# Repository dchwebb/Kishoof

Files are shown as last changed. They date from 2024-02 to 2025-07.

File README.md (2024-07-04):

# Kishoof

## Overview

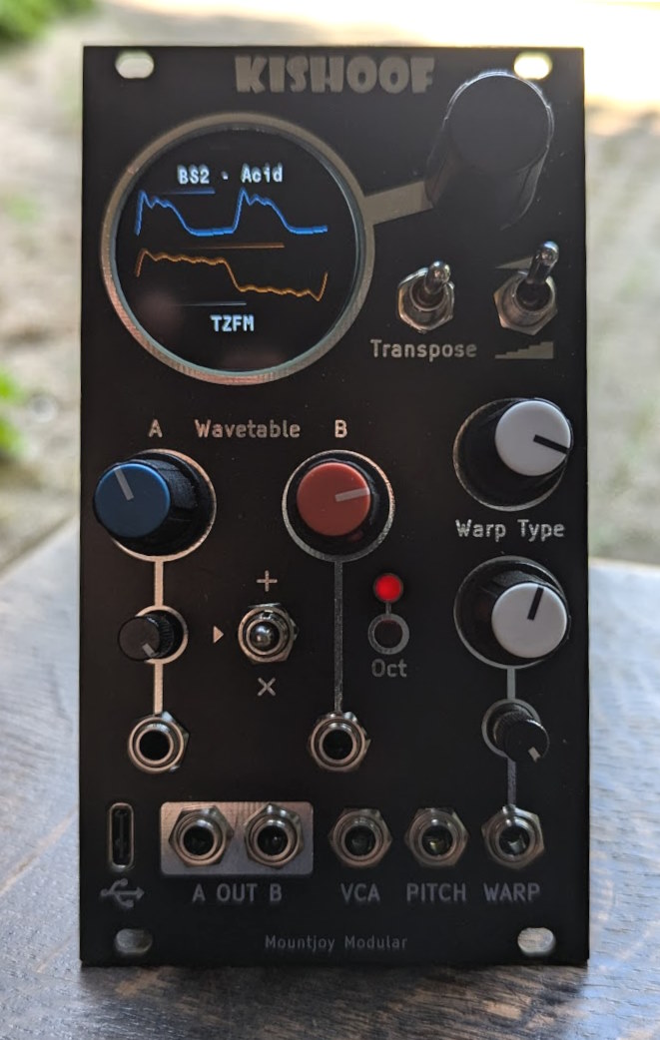
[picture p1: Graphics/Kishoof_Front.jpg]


Kishoof is a Wavetable synthesizer designed for use in a Eurorack modular system. A dual channel architecture allows simultaneous playback of two channels each offering a different range of capabilities. Wavetables are held in 64MB of internal flash storage which is exposed as a USB disk drive via a front-panel USB C connector.

Two modes of operation are available with one stepping between individual wavetable frames and one smoothly interpolating between frames. In stepped mode channel A and B can each play any of the available wavetable frames. In smooth mode Channel A plays the loaded wavetable and channel B plays an internal wavetable that can be configured to hold a range of standard waveforms and harmonics.

A warp engine allows a range of warping effects to alter channel A's signal, with Bend, Squeeze, Mirror and though-Zero Frequency Modulation from channel B available. Channel B can be modulated via addition (mixing) and multiplication (ring modulation) with channel A and its playback direction can be reversed. Dynamic anti-aliasing filters eliminate aliasing regardless of modulation settings. 

A circular TFT LCD display shows both or either channel's waveform with any warping and modulation applied. A serial console available over a USB virtual COM port allows advanced configuration, calibration and trouble-shooting facilities.

The module was designed in conjunction with musician Tal Shoshani who produced the following demonstration video:

IMAGE ALT TEXT HERE (https://www.youtube.com/watch?v=ltlQT8CrSRk)

- **[Operation Manual](Kishoof_Manual.md)**

## Technical

Kishoof is based on an STM32H7B0 microcontroller clocked at 280MHz. Internal flash storage uses a Macronix MX25LM51245G 512Mbit NOR flash IC, clocked at 76.8MHz. The flash is controlled by the MCU using OctoSPI.

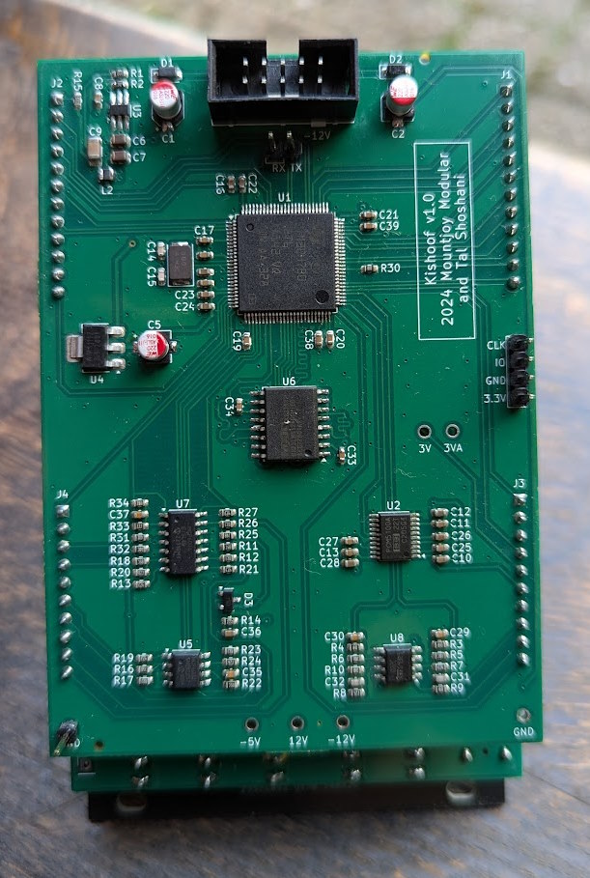
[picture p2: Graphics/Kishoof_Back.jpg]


A TI PCM5100APW audio DAC is used for wavetable playback, operating in stereo at 48KHz. This is interfaced to the MCU over I2S. The MCU's internal 12 bit ADCs receive potentiometer and scaled Control voltage inputs.

The display is a circular 1.28 inch 240x240 IPS TFT LCD with GC9A01 Driver and is controlled via SPI. USB is connected via a front-panel USB C connector with ESD Protection.

**Construction**

The module is constructed of four PCBs: Component board, Control board, LCD daughterboard and Front Panel. The Component board is a 4-layer board. All others are 2 layer.

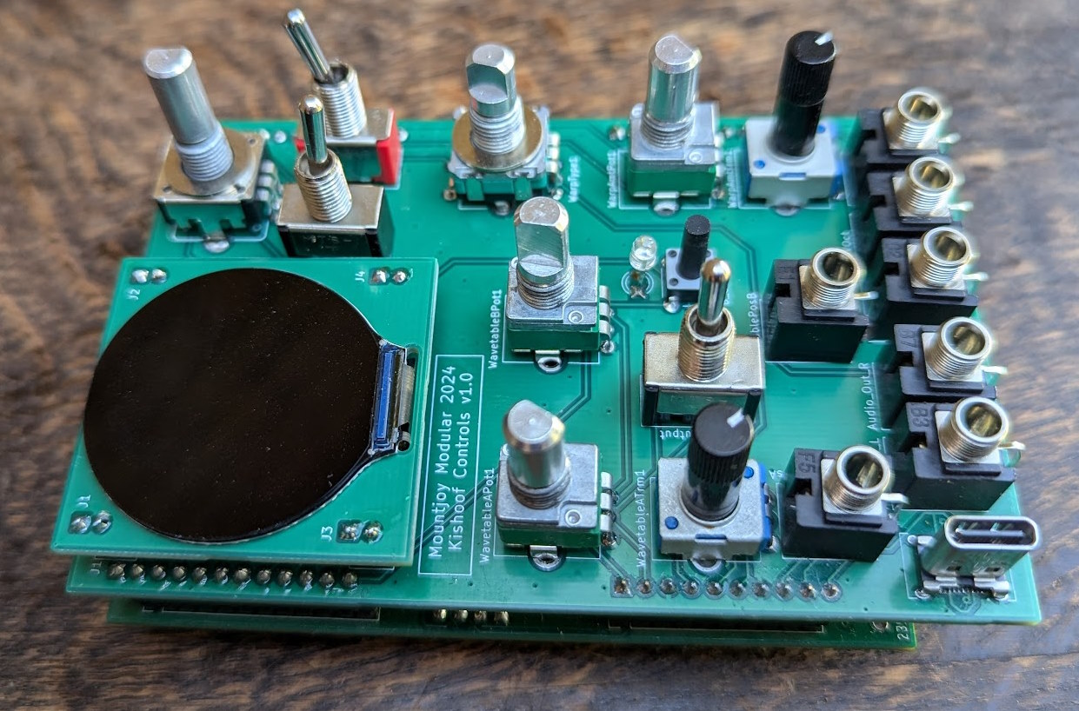
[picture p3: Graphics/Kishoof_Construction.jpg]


Circuit Design and layout using Kicad v8:

[Components schematic](Hardware/Kishoof_Components.pdf)

[Controls schematic](Hardware/Kishoof_Controls.pdf)

**Firmware**

Firmware written in C++20 using STM32CubeIDE version 1.15.1 and is available [here](Kishoof)

## Power

Digital power is supplied through a TI TPS561201 3.3V switching power supply and analog power via a 3.3V linear regulator.

- +12V current draw: 149 mA
- -12V Current draw: 7 mA

## Hardware Errata and Potential fixes

- VCA input should be normalised to a ~7V signal (currently bodged to 3.3V).
- Improve ground return paths on LCD daughterboard
- Invert LCD daughterboard to make orientation easier, and move pads towards cutout
- Fix footprint for switched potentiometer (Warp Type)

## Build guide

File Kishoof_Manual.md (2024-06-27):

# Kishoof Manual

## Table of Contents

- [Controls](#controls)
- [Wavetables and Playback Mode](#wavetables-and-playback-mode)
  * [Smooth Playback Mode](#smooth-playback-mode)
  * [Stepped Playback Mode](#stepped-playback-mode)
- [Warping and Modulation](#warping-and-modulation)
  * [Channel A Modulation](#channel-a-modulation)
  * [Channel B Modulation](#channel-b-modulation)
- [Startup configuration](#startup-configuration)
- [Calibration Configuration and the Serial Console](#calibration-configuration-and-the-serial-console)
  * [Calibration](#calibration)
  * [Flash Storage Management](#flash-storage-management)
  * [Safe Mode and full Flash erasing](#safe-mode-and-full-flash-erasing)
- [Firmware Upgrade](#firmware-upgrade)

## Controls

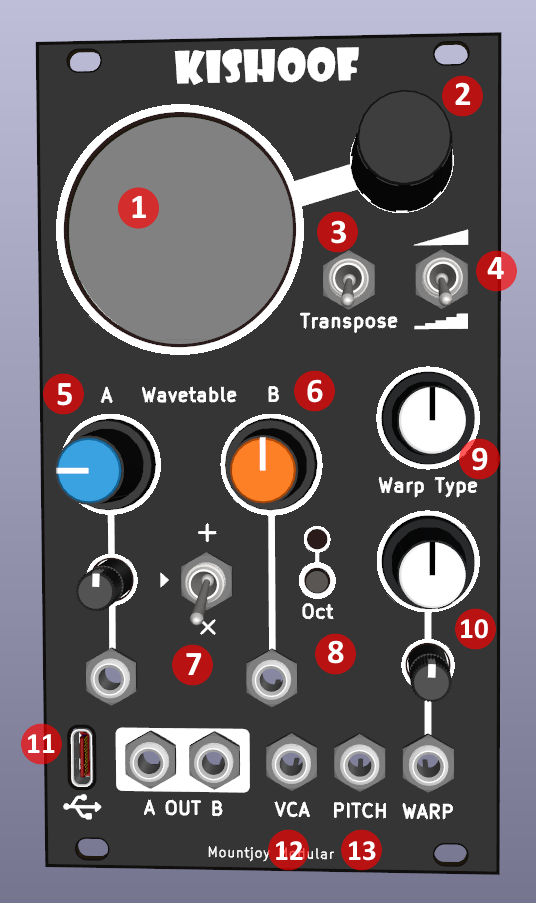
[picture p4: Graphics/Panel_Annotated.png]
Panel


**1. LCD Screen** Displays name of selected wavetable, waveforms, wavetable and warp positions and warp type

**2. Encoder** Selects wavetables; press to change display from both to either wavetable

**3. Transpose**: 3 position control allowing octave up, down or normal for both channels

**4. Playback Mode** Up position plays a smoothly interpolated wavetable in channel A and a preset wavetable in channel B; In the down position both channels can play any wavetable frame, without interpolation

**5. Channel A Wavetable** Wavetable frames are selected by a combination of the knob and CV via attenuator

**6. Channel B Wavetable** Wavetable frames are selected by a combination of the knob and CV input

**7. Channel B Modulation** Modulate channel B output: Up position mixes in channel A; down position multiplies with Channel A (ring modulation)

**8. Channel B Octave** When button is pressed (LED on) channel B is one octave down from channel A

**9. Warp Type** Selects channel A warp type (Squeeze, Bend, Mirror, Through-Zero FM). Press knob to reverse direction of channel B wavetable

**10. Warp Amount** Select the amount of modulation via knob and attenuatable CV

**11. USB C device** Used to access the internal storage as a USB drive; also provides a serial console for advanced utilities and configuration

**12. VCA input** Attach an envelope CV to control output volume of module

**13. Pitch** Attach a 1 volt per octave CV to control pitch over 6 octaves

<br />
<br />

## Wavetables and Playback Mode

Kishoof plays back wavetables from an internal 64MB flash storage system. By connecting the module to a host via USB C the internal storage can be accessed and wavetables stored.

Supported Wavetable formats:
- wav file format
- Either 32 bit floating point or 16 bit fixed point
- Mono
- 2048 samples per frame
- Up to 256 frames

Wavetables are selected with the rotary encoder. If wavetables are stored in sub-folders these will be shown in yellow text and can be accessed by pressing the encoder button. If a wavetable is corrupt or in an unsupported format an error is shown on attempting to load:

- **Fragged**: Wavetable is fragmented in the file system
- **Corrupt**: The wav header cannot be read
- **Format**: Not 32 bit floating point or 16 bit integer
- **Channels**: Not mono
- **Empty**: No file data

### Smooth Playback Mode

With the playback mode switch in the up position, Channel A will playback the selected wavetable smoothly interpolating between the frames as the wavetable position is moved.

In this mode channel B plays a special internal wavetable which is user configurable via the console. This can contain up to 10 different wavetable frames chosen from: Sine at 1, 2, 3, 4, 5 or 6 times base frequency, Square, Saw, Triangle waves. This is generated using additive synthesis and is configurable in the console - use the command **help add** for instructions.

### Stepped Playback Mode

With the playback switch in the down position, wavetable frames are selected individually and not interpolated. In this mode both channel A and B can play any frame from the same wavetable.

<br />
<br />

## Warping and Modulation

### Channel A Modulation

The Warp Type knob selects the type of modulation applied to channel A:

- **Squeeze** - Warp amount to the left stretches the wave out from the center; to the right squeezes it into the middle

- **Bend** - Progressively squashes the wave from the right to the left

- **Mirror** - The first half of the wave cycle plays the wave forwards, the second half backwards. The Warp amount stretches the wave progressively from the outside to the inside

- **TZFM** - Applies through zero frequency modulation from channel B to channel A: as channel B's wave increases channel A's wavetable is played faster and vice versa. The overall amount of frequency modulation is proportional the base pitch so this will not produce enharmonic tones (as with standard FM).

### Channel B Modulation

The channel B modulation switch affects channel B's output: In the up position channel A's signal is added/mixed  and in the down position the two signals are multiplied (ie ring modulated).

Channel B can also be reversed by clicking the Warp Type button - orange arrows are shown at the bottom of the display to indicate if this is on.

Channel B can also be switched an octave down relative to channel A. This will affect channel A in TZFM mode, unlike the add/multiple modulations.

<br />
<br />

## Startup configuration

Kishoof has a mechanism to store its current settings in the microcontroller's internal non-volatile memory. Settings that are stored are:

- Calibration data
- Currently selected wavetable
- Channel B octave button state
- Channel B reverse wavetable playback state
- UI wavetable display settings

Changes are batched and are only written after 60 seconds since the last change has elapsed. Changes are stored sequentially over the internal non-volatile memory to avoid excessive wear.

So that configuration changes do not interfere with audio output there are a maximum number of changes that can be written in a single session, after which a restart is needed to free up additional memory. Total storage for config data is 24 kBytes and each configuration block is around 48 bytes so up to 512 configuration blocks can be saved per session.

If the configuration becomes corrupt or does not write correctly even after restarting the command **clearconfig** from the console (see below) will blank the internal storage.

<br />
<br />

## Calibration Configuration and the Serial Console

When connecting a USB C cable to the module a virtual COM port provides a serial console for calibration, configuration and trouble-shooting.

Use an appropriate serial console application (Termite, Putty etc) to connect. Type 'help' for a list of commands and 'info' for module information including firmware build date, calibration settings etc:

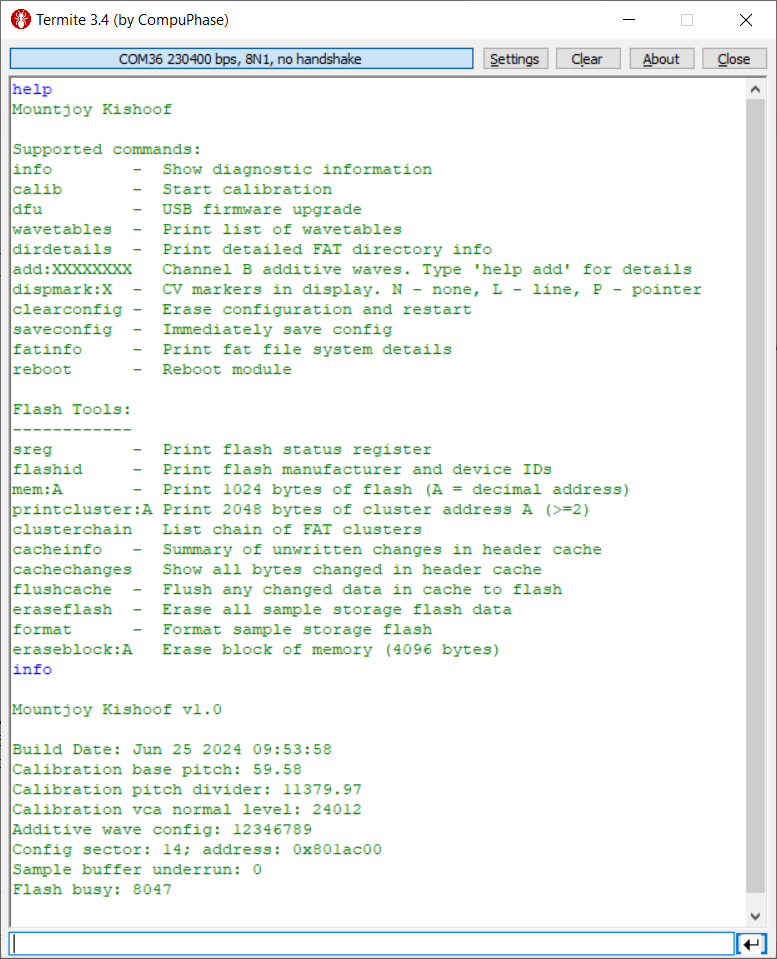
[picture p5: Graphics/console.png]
Console


### Calibration

Calibration is used to configure the appropriate scaling for the 1 volt per octave signal. It also sets the normalisation level of the VCA control so the output is at full level with no envelope connected.

To calibrate it is necessary to generate a 0V and 1V signal which represent the lowest two C octaves the module can output. The calibration process will show its readings of the applied signals so try different octaves if the readings look out.

Type 'calib' to begin, check the measured values against the expected values and type 'y' to continue or 'x' to abort:

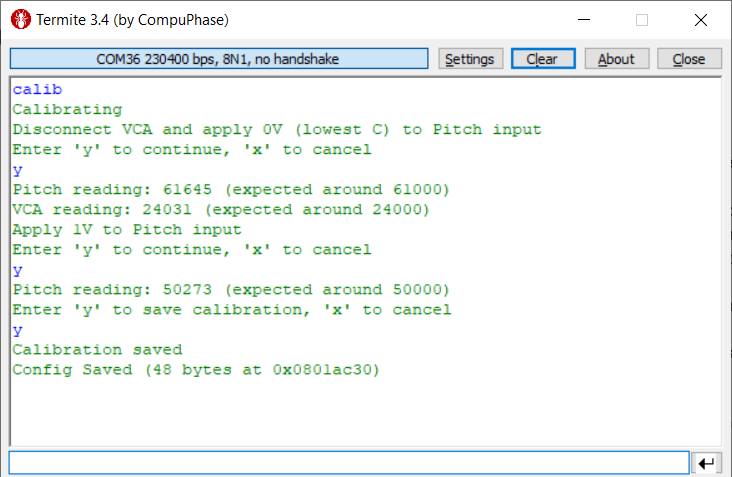
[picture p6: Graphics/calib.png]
Calibration


### Flash Storage Management

An internal 512Mbit NOR flash chip is used to store up to 64 MB of wavetable data. The storage must be formatted in FAT16 format and it is recommended to use the internal 'format' command to initialise the storage correctly. This also creates dummy Windows indexer files which allow the module to track and discard spurious changes that create excessive wear to the storage.

There are various commands that provide low-level trouble-shooting and diagnostic information on the internal storage. The following commands are available:

**format** reformats the internal storage, erasing all wavetables and folders

**wavetables** displays a list of all recognised wavetables and folders:

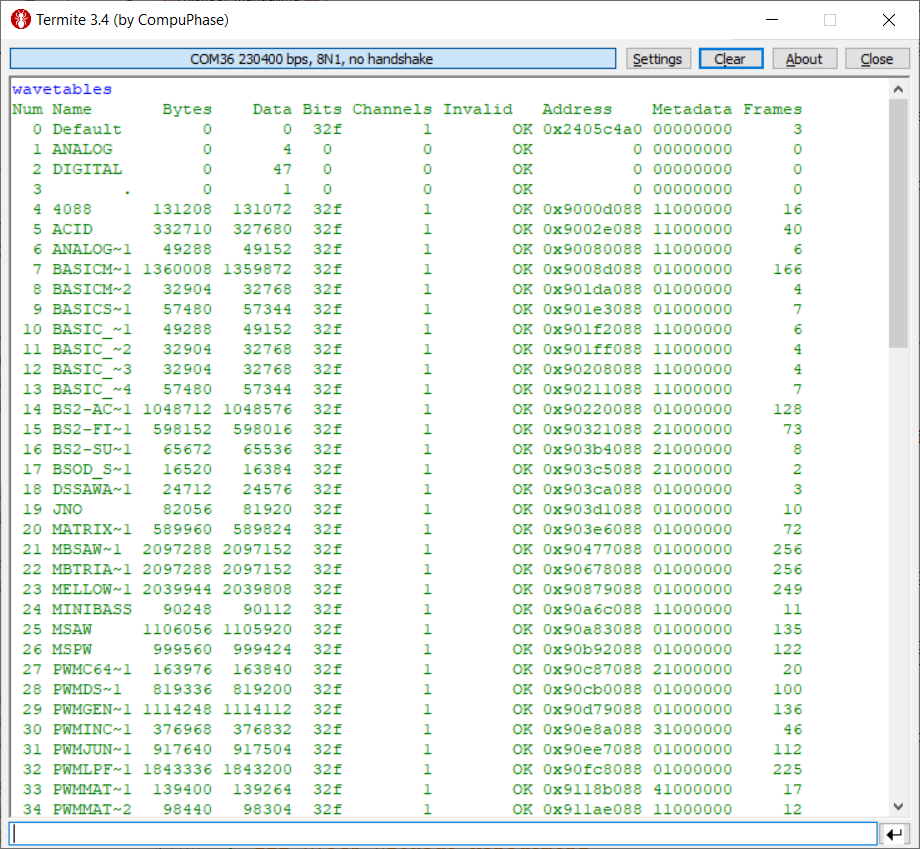
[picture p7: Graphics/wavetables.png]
Wavetables


**dirdetails** displays a detailed listing of files on the internal storage:

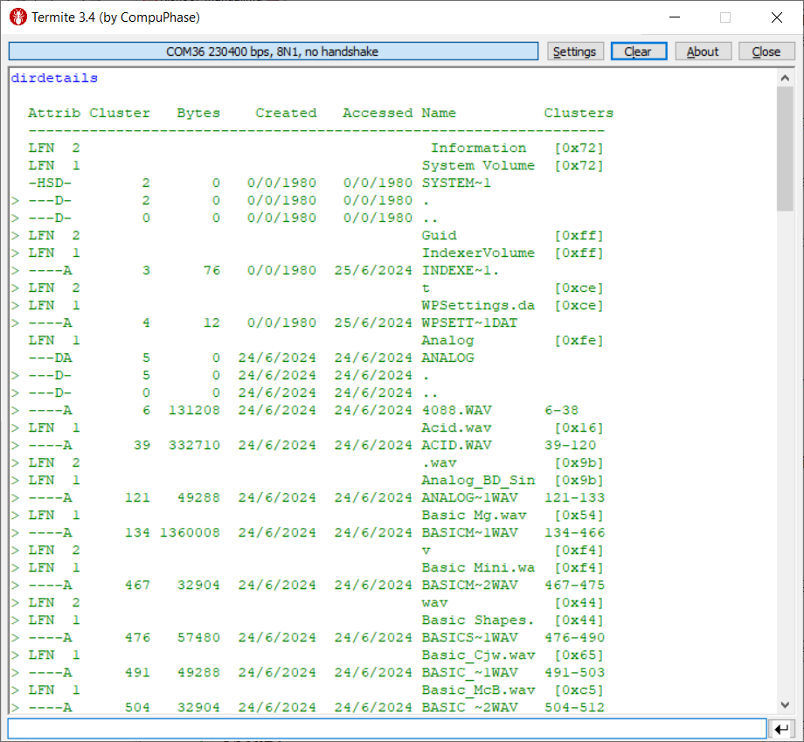
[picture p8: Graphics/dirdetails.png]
Directory Details


### Safe Mode and full Flash erasing

If the storage becomes badly corrupted the module may have trouble starting. In this situation access safe mode by power cycling the module with the encoder button depressed.

This will not mount the USB drive, will not mount the flash storage, will not load the configuration settings and allows complete erasing of the flash storage.

In safe mode to completely erase the internal flash storage type **eraseflash**.

<br />
<br />

## Firmware Upgrade

A mechanism is provided to upgrade the firmware over USB. Note that the latest firmware for the module can be found here: [Kishoof.elf](Kishoof/Debug). Download the file (use raw format to get the file in binary format).

In the serial console type **dfu**. This will reboot the module into DFU (Device Firmware Upgrade) mode.

Run the STM Cube Programmer software available here: [STM Cube Programmer](https://www.st.com/en/development-tools/stm32cubeprog.html).

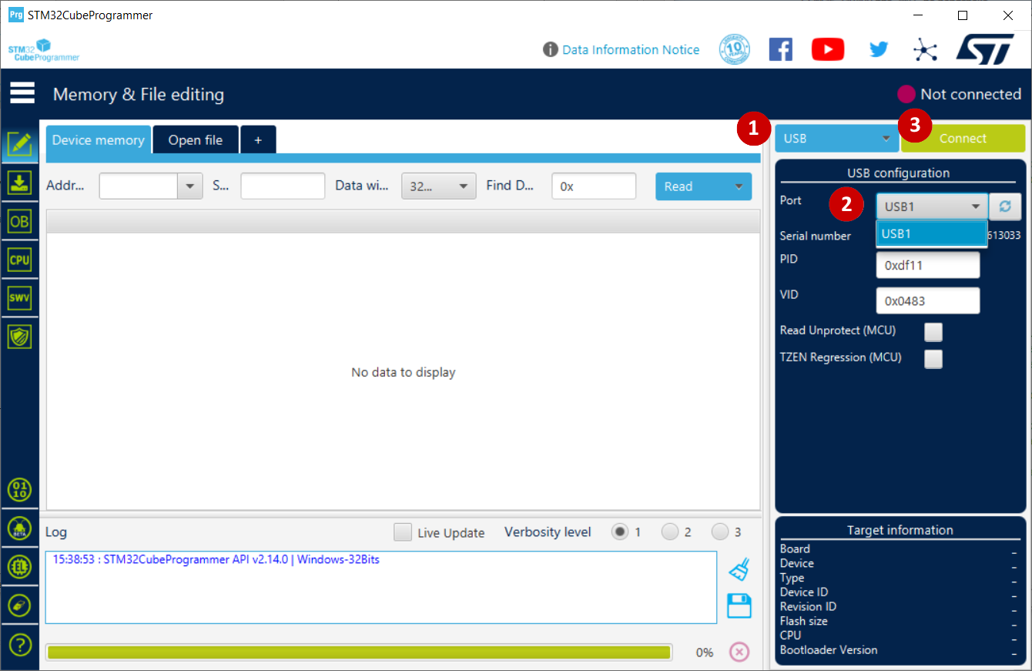
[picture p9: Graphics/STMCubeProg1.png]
Programmer


1. Select USB connection
2. Click Refresh and select the appropriate USB port (USB1 here)
3. Click Connect

<br />
<br />

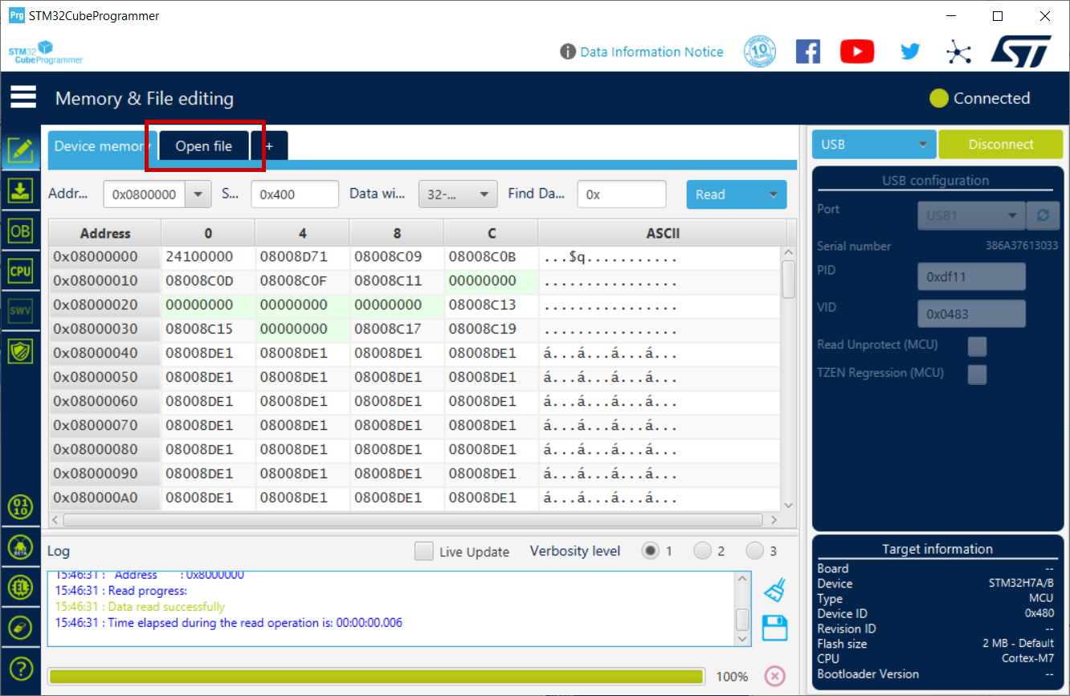
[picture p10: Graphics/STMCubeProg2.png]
Programmer2


- Click 'Open file' and navigate to the Kishoof.elf firmware file downloaded from Github.

<br />
<br />

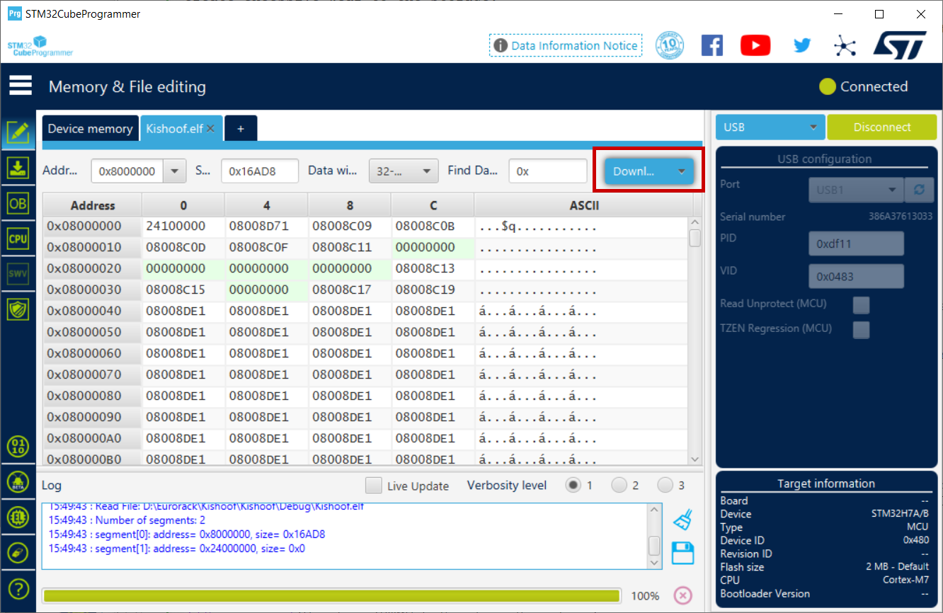
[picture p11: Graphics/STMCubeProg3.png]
Programmer3


- Click the 'Download' button to transfer the firmware onto Kishoof.
- Restart the module. Note you can use the console command **info** to view the firmware build date to confirm an upgrade has succeeded.

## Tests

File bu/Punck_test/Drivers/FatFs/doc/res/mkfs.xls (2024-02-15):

Drive Size [sector] | ANY+SFD au = 0 |  |  | ANY+SFD au = 4096 |  |  | EXFAT+FAT32+SFD au = 0 |  |  | EXFAT+SFD au = 0 |  |  | FAT32+FAT+SFD au = 0 |  |  | FAT32+SFD au = 0 |  |  | FAT+SFD au = 0
 | Type | csize | n_clust | Type | csize | n_clust | Type | csize | n_clust | Type | csize | n_clust | Type | csize | n_clust | Type | csize | n_clust | Type | csize | n_clust
1024 | FAT12 | 1 | 987 | FAT12 | 8 | 123 |  |  |  |  |  |  | FAT12 | 1 | 987 |  |  |  | FAT12 | 1 | 987
1025 | FAT12 | 1 | 988 | FAT12 | 8 | 123 |  |  |  |  |  |  | FAT12 | 1 | 988 |  |  |  | FAT12 | 1 | 988
1026 | FAT12 | 1 | 989 | FAT12 | 8 | 124 |  |  |  |  |  |  | FAT12 | 1 | 989 |  |  |  | FAT12 | 1 | 989
1027 | FAT12 | 1 | 990 | FAT12 | 8 | 124 |  |  |  |  |  |  | FAT12 | 1 | 990 |  |  |  | FAT12 | 1 | 990
1028 | FAT12 | 1 | 991 | FAT12 | 8 | 124 |  |  |  |  |  |  | FAT12 | 1 | 991 |  |  |  | FAT12 | 1 | 991
1029 | FAT12 | 1 | 992 | FAT12 | 8 | 124 |  |  |  |  |  |  | FAT12 | 1 | 992 |  |  |  | FAT12 | 1 | 992
1030 | FAT12 | 1 | 993 | FAT12 | 8 | 124 |  |  |  |  |  |  | FAT12 | 1 | 993 |  |  |  | FAT12 | 1 | 993
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

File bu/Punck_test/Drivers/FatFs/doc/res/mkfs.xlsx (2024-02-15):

sz_vol [sector] | .fmt = ANY .au_size = 0 |  |  | .fmt = ANY .au_size = 4096 |  |  | .fmt = EXFAT+FAT32 .au_size = 0 |  |  | .fmt = EXFAT .au_size = 0 |  |  | .fmt = FAT32+FAT .au_size = 0 |  |  | .fmt = FAT32 .au_size = 0 |  |  | .fmt = FAT .au_size = 0
 | Type | csize | n_clust | Type | csize | n_clust | Type | csize | n_clust | Type | csize | n_clust | Type | csize | n_clust | Type | csize | n_clust | Type | csize | n_clust
1024 | FAT12 | 1 | 987 | FAT12 | 8 | 123 |  |  |  |  |  |  | FAT12 | 1 | 987 |  |  |  | FAT12 | 1 | 987
1025 | FAT12 | 1 | 988 | FAT12 | 8 | 123 |  |  |  |  |  |  | FAT12 | 1 | 988 |  |  |  | FAT12 | 1 | 988
1026 | FAT12 | 1 | 989 | FAT12 | 8 | 124 |  |  |  |  |  |  | FAT12 | 1 | 989 |  |  |  | FAT12 | 1 | 989
1027 | FAT12 | 1 | 990 | FAT12 | 8 | 124 |  |  |  |  |  |  | FAT12 | 1 | 990 |  |  |  | FAT12 | 1 | 990
1028 | FAT12 | 1 | 991 | FAT12 | 8 | 124 |  |  |  |  |  |  | FAT12 | 1 | 991 |  |  |  | FAT12 | 1 | 991
1029 | FAT12 | 1 | 992 | FAT12 | 8 | 124 |  |  |  |  |  |  | FAT12 | 1 | 992 |  |  |  | FAT12 | 1 | 992
1030 | FAT12 | 1 | 993 | FAT12 | 8 | 124 |  |  |  |  |  |  | FAT12 | 1 | 993 |  |  |  | FAT12 | 1 | 993
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

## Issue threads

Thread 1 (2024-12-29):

Warp Type Potentiometer with switch

KeenVox, 2024-12-29:
Hi again, :)

do you have any directions where to get the WarpType pot with integrated switch?  I'm having a hard time finding that part.

Or should it be an encoder?

dchwebb, 2024-12-30:
I think the part I used was this one:

https://www.mouser.co.uk/ProductDetail/Bourns/PRS11R-415F-S103B1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

KeenVox, 2024-12-30:
Ah perfect, thank you. I really couldn't find it...
Next modul to be finished. Love your stuff. :)

Am 30. Dezember 2024 15:41:55 schrieb dchwebb ***@***.***>:
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

KeenVox, 2025-01-06:
Is the ChB-Output switch an On-off-On switch as it is shown in the shematic or is it an on-on switch? In the manual it only speaks about the two modulation modes not if there's a "off" position in the middle.

dchwebb, 2025-01-06:
It is an On-off-On switch. The 'off' position is just channel B's output and the other two positions select channel B mixed or multiplied with channel A.

KeenVox, 2025-01-10:
Finished and working. Thank's again for the support.

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

dchwebb, 2025-01-10:
Awesome news - I hope you enjoy it.

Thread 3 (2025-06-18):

Hardware or Firmware Problem

tsanderakis, 2025-06-18:
Fighting in the moment with my fresh built Kishoof but can`t get the USB Connection working. Win10 is telling me Code 43. Can`t find device description. Is there an additional Win Driver needed, did I make something wrong when soldering or flashing? What to do? Thany you

dchwebb, 2025-06-19:
Could you supply some more information:

1. Is the rest of the module working?
2. Could you send a screenshot of the error 43? I don't think I have seen this before.
3. I use [USB Device Tree viewer](https://www.uwe-sieber.de/usbtreeview_e.html) for all my USB troubleshooting. Could you try installing that and see what that shows?

Without more information my first guess would be that if the rest of the module is working then this is likely to be a soldering issue on the USB socket. The fact that it appears Windows is seeing some kind of activity implies that the microcontroller is getting the VBUS signal and pulling D+ high. If that is the case at least some of the soldering is working. It could be something like D+ and D- are shorted together or D- is not connected.

In any case if you can answer the first three questions I could recommend some tests that would get to the next stage.

tsanderakis, 2025-06-19:
Your first guess is right and I think a soldering issue on the USB connector. Just kicked one hour ago the protector out and the two resistors around. Still making Ding Dong when connecting. Testet it with a new USB connector fresh out of the box and no Ding Dong. So now clear what it is. Tried to reflux and also tried to take solder away with wick without success. So I have to wait until an adaptor arrives for better messurement. It is on the way.
https://www.ebay.de/itm/187013100646
If it does not fit I orderd also a small extension. Hope that all wires are going through. Dont want to kick Pots out.
https://www.ebay.de/itm/386144854364?var=654675779984

There is also a small problem with the output but I think that I can find it. Wrong parts in wrong place?
When I touch with my finger right of 6004 onto the 0603 parts I can hear something in the background. So seems that DAC is working and its something wrong around these amplifying OP amps. I can also hear a "working" octave switch.
Pots and switches all working, display is fine without any problem and so far everything looks fine.

A little problem for the future to keep Kishoof alive for the next years is the protector, which is no more avaiable from big distributers  like Mouser or Digikey. Ordered my protectors from Aliexpress. In Europe there are some more at Comet in Bulgaria, but no Paypal. After having bad experience  with credit cards I try to use only Paypal. This chip does not look like rocket science and there are more of these on the market but no pin combatible. So if you have the big time and your Kicad open.........

So I let you now more in the next few days from my way to a working Kishoof.
Thank you for your help and fast response.

dchwebb, 2025-06-19:
I'm guessing you mean the USB ESD protection (STF202-22T1G chip)? If so that would be very easy to switch in the design. Also I have realised that the resistors R1 and R2 are not necessary as the module only works with USB 2.0 which does not use the CC pins on the USB-C connector. Let me know if you want a revised PCB design.

I think this STM part actually has some ESD protection on the USB input so at a pinch you could probably just jumper the D- to DM and D+ to DP and get unless you get a really big spike that should be fine.

You could do some measurement on the USB connection using the ESD chip as the test point. You can check if the D+/D- pins are shorted using a multimeter. Also check if either is shorted to ground or VBUS - you can see the various connections here:

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

KeenVox, 2025-06-19:
@tsanderakis I've build the kishoof a couple of months ago and can confirm, that if everything is soldered correctly the pcb works like it should.

I'm not 100% sure, but I think I ordered two STF202-22T1G chips. I can look in my list this evening if you like? If I have one, maybe I could send it to you. Would be from germany... :)

tsanderakis, 2025-06-19:
Just found a cold joint in the VCA department. Now I have nice and beautifull output on  OUT B.  OUT A for the moment not mounted because I need the space for my hot iron. Had my Westlicht Sequencer connected to it and think its all working fine.
So finish now for today.

tsanderakis, 2025-06-20:
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
One hour ago the adaptor came in and result was that there was a short between USB_D- and USB VBus. Could fix it with flux and iron.
Now I can go on

tsanderakis, 2025-06-21:
Did some final tests last night and here it is and working. One more Kishoof in this world. Big **Thank You** for sharing your designs.
Think next month I will try the scope.

dchwebb, 2025-06-21:
Great news! Hope you enjoy it.

tsanderakis, 2025-06-23:
Thinking I will take the risk and waiste maybe my money buying a bigger one in beginning on next month. Have to order anyway parts from Digikey and then I let you know what is´´is going on. Dont think that my then planned second Kishoof will end up in magic smoke.
And when the firmware is not working with this chip, bad luck and my fault.

tsanderakis, 2025-06-23:
In Europe???

tsanderakis, 2025-06-23:
If it is USA this will be maybe difficult from here. Don`t know what`s going on meanwhile with tarrifs. The other way is still working good 2 days with mouser from Texas to Upper Neandertal Germany by Fedex. And if I find one I will order one more  and send it to you.

dchwebb, 2025-06-23:
I can't find them anywhere. All the searches bring up is the BGA version.

tsanderakis, 2025-06-23:
https://www.digikey.de/de/products/detail/macronix/MX66L1G45GMI-08G/7796743
But I think that this will not work, because it is to different.
So no chance for me, You were right.

tsanderakis, 2025-06-23:
That's life and sometimes my big dreams don´t come true.
But 160 Wavetables is not to bad.
When I remember back in the 80s the Yamaha DX7 / TX7 we were living with 32 Patches. I try to organize these wavetables what I habe into let`s call it banks and from a computer you can replace them in a simple way in a very short time. Think there is no need for any improvements and we can close it now.
Started one more Kishoof building this afternoon and think a pair ist better then one in my system.
Think next will be Punck or Oscar in August.

tsanderakis, 2025-06-24:
Yesterday evening when a little bit playing around something was confusing me. When I try to copy wavetables back to my computer Kishoof is freezing and no more working and not found by the computer. After switching power off / on it is found again by Windows. Try to copy again, same problem. Frozen. Any Idea? Or is it just only one way?

tsanderakis, 2025-06-24:
yes, and was swimming 2 hours this morning. Sitting in front of a soldering station is not so good for my old bones and sugar level, so I try to do my best.

dchwebb, 2025-06-25:
The main problem with it freezing when copying back files from the drive is that the USB is contending with the Wavetable playback and the flash storage is not fast enough to serve both.

I have implemented a potential fix which is to block wavetable playback while copying files off the Kishoof flash storage. It seems to be a lot better, but I am not sure this is a 100% fix.

tsanderakis, 2025-06-25:
Interesting. This time not Kishoof freezing, but my Laptop. No mouse. Kishoof stays alive. When pulling the USB cable going from Laptop to Kishoof my mouse is back. But Kishoof does not show up as a drive. After cold start Kishoof is back and showing its drive.

tsanderakis, 2025-06-25:
Yep. These were  ~7 or 8 and only No. 1 arrived at  the Laptop. At No. 2 freeeze. Finished my second Kishoof this evening to have a second one for comparing problems. Then I deleted on this one the wavetables inside 2 folders I had on the drive. But impossible to delete the emty folders. So had to take Termite, format the drive and then it was possible to copy Wavetables onto the drive again, but the speed was so slow comparing to the Version of the firmware before.
Bad weatherforcast for tomorrow so more time and I will do some more tests and also on both Kishoofs.

tsanderakis, 2025-06-26:
Looks good now after playing around for 3 hours.
Don`t know what was going on yesterday evening, but this morning everything was fine and I`m happy. Full Moon?
I took the lastest .elf  und used termite to open USB and then STM32CubeProgrammer to send this .elf to Kishoof. Last week when starting and the USB was not working I used the STM Disco Board.
Ok, you cannot torture this tiny little chip by dragging, dropping, copying, deleting or whatever like your hard drive. Important is proper format.
Dont`t know if this is low lewel and reset to zero. But uploading and downloading the whole content working and speed of this chip was around 120kb without freezing anything on both sides.
Have now 463 files in 13 folders and this isok for me.  But it is also good that this complete dump is possible, because I had to change some foldernames being to long. Ok, luxury is when long foldernames are scrolling but think not nessesary.
Can`t remember with FAT16 how many files can go into one folder and the length of the filenames. Something for the usermanual in big red letters and that the people should use better often the format command and sending everything in one batch if it is not in there. I have here 3 SD card sampleplayers working. This is Tesseract Nutella Tsunami, Tesseract Tukra and VPME Quaddrum. But low level formating ist so important when working.
So I think we can really close now issue no. 3
Thanx for your help.

tsanderakis, 2025-06-26:
No need to kill the pig. Keep it alive.

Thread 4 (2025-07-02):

Calibration Question

KeenVox, 2025-07-02:
Hi,

as far as I could test, all works well with my Kishoof, but when using the calibration over the terminal I get this reading for the VCA:

Pitch reading: 62554 (expected around 61000)
VCA reading: 62209 (expected around 24000)

Pitch reading: 51123 (expected around 50000)

Is this anything I should be worried about?

dchwebb, 2025-07-02:
The pitch readings are fine. However the reason that the VCA is reading incorrectly is due to an error I made on the original design.

The VCA is designed to allow you to connect an envelope (or similar) to control the level of the module without needing to use a separate VCA.

The VCA normal connection (pin 2) should ideally be connected to a Eurorack full level signal (say around 7v). Unfortunately I connected the normal of the VCA jack to ground. This means that if you want to use the module with external level control you need to feed in a high voltage into the VCA input.

I put a bodge workaround into the module which is to connect the normal to 3.3V as that was the signal I had available on the control board. There is then a simple software routine that checks if the level is stuck on 3.3V and assumes that the VCA is not in use, outputting a full level signal.

So you have a couple of options - always have a signal connected to the VCA input, or bodge the connection on the control board. This involves removing the connection between pin 2 of the VCA to ground (which involves cutting the traces on both sides of the PCB) and then running a bodge wire to the nearest 3.3V connection (eg on the warp amount trim pot pin 1).

KeenVox, 2025-07-03:
Ah, okay.

Just to make sure. You mean the middle pin that needs to be connected to 3.3V after cutting the traces?

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

dchwebb, 2025-07-03:
That's correct. For a simpler fix you could also try using a pull-up resistor (say around 10k) onto pin 3 from 3.3V.

This should mean that if you don't apply any signal to the VCA input it should be pulled up to 3.3V, but if you do apply a signal it should override the fairly weak pull-up signal.

The advantage of this approach (untested) is that you should be able to try it without cutting any traces.

KeenVox, 2025-07-03:
Pull-Up sadly didn't work. I tried with 10k and 1K.

I cut the traces and made a bodge to 3.3V as you suggestet earlier. Now calibration works as intended.

Thx!

tsanderakis, 2025-07-08:
After starting Kishoof yesterday evening without calibration I was a little bit in Panic that I was doing something wrong.
But after calibration I have sound again.
For the moment it looks good.
Will now reassemble the module,  Try to put a little bit transparent film as a protection between display and faceplate. Found something cheap.
https://de.aliexpress.com/item/1005006819558791.html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
Normaly this is for baking cake.

This afternoon I will do the patch to my second module. Everything slowly, because old man and still learning, but I understand more and more what to do. When loading Wavetables into Kishoof, I stumbled somewhere on the net upon a rip from the original Eproms from the PPG from the 80ties. The are converted into wav and were working. Big fun.

Here is the system data from my first module

calib
Calibrating
Disconnect VCA and apply 0V (lowest C) to Pitch input
Enter 'y' to continue, 'x' to cancel
y
Pitch reading: 65230 (expected around 61000)
VCA reading: 63071 (expected around 24000)
Apply 1V to Pitch input
Enter 'y' to continue, 'x' to cancel
y
Pitch reading: 53743 (expected around 50000)
Enter 'y' to save calibration, 'x' to cancel

hope it is ok

dchwebb, 2025-07-08:
That calibration reading for the VCA doesn't look right - did you run it with nothing connected? It looks like it may connected to ground from that reading.

tsanderakis, 2025-07-08:
Yes, there was nothing connected to VCA input.

tsanderakis, 2025-07-08:
calib
Calibrating
Disconnect VCA and apply 0V (lowest C) to Pitch input
Enter 'y' to continue, 'x' to cancel
y
Pitch reading: 65119 (expected around 61000)
VCA reading: 23925 (expected around 24000)
Apply 1V to Pitch input
Enter 'y' to continue, 'x' to cancel
y
Pitch reading: 53642 (expected around 50000)
Enter 'y' to save calibration, 'x' to cancel
y
Calibration saved
Config Saved (48 bytes at 0x0801bbf0)
 This is Kishoof No. 2 with patch and think this looks better.
Will put now everything together and hope it stays alive.

Then we will see maybe tomorrow if I can rescue No. 1

dchwebb, 2025-07-08:
Yup - 2 looks good. Not sure what's up with 1, though. Are the 3.3v power rails good?

tsanderakis, 2025-07-08:
This is what I really try to check tomorrow. For today is finish and I will play a little bit around with No. 2.
Last thing I did today before having food and a beer was checking if my STM Disco board finds the processor.
No. No chance. The LED stays on and the switch for it also not working. So I hope that this new error was not my fault when doing the patch. I checked the middle pin with my multimeter and it was free, but you never know. Ok, I can swap the boards but don`t want to take the risk killing a second processor board.
Will check tomorrow if the 3,3V are there where they belong. No. 1 was working for around 2 weeks. Maybe some C`s to weak?
I had not all C`s laying around and repaced some 0603 by bigger 0805. If I`m lucky the 0603 stuff is coming from Mouser tomorrow so I can replace these parts. This time Mouser was totally slow. Ordered on thursday morning last week.
So tomorrow I will go on and let you know.

tsanderakis, 2025-07-09:
Kishoof No. 1
Seems that something is wrong with L2. On right side there are no 3,3V. Think it is blown and dead. So now Ihave to find out why.
But later this day. A friend, guitarplayer, was calling me for help with his pedal board.

tsanderakis, 2025-07-09:
Kishoof No. 1 a little bit back to life, but still mysterious behaviours. When starting it with encoder knob pressed, I have my screen back and have audio out on both channels .Can talk to it fe. help,, calibrate, but when formatting it makes a reset after and starting again in "normal" mode with black screen and nothing to hear on the outputs, so frozen. Ram Drive does not appear under windows and so no chance to send Wavetables. First fault I found was that the upper pin of VCA In had no more connection to J4, so did it now with a wire. Went something wrong when patching. But whats up with the rest, especially with the microprocessor, for the moment is a big mystery.

calib
Calibrating
Disconnect VCA and apply 0V (lowest C) to Pitch input
Enter 'y' to continue, 'x' to cancel
y
Pitch reading: 65204 (expected around 61000)
VCA reading: 24803 (expected around 24000)
Apply 1V to Pitch input
Enter 'y' to continue, 'x' to cancel
y
Pitch reading: 53740 (expected around 50000)
Enter 'y' to save calibration, 'x' to cancel
y
Calibration saved
Config Saved (48 bytes at 0x0801a030)

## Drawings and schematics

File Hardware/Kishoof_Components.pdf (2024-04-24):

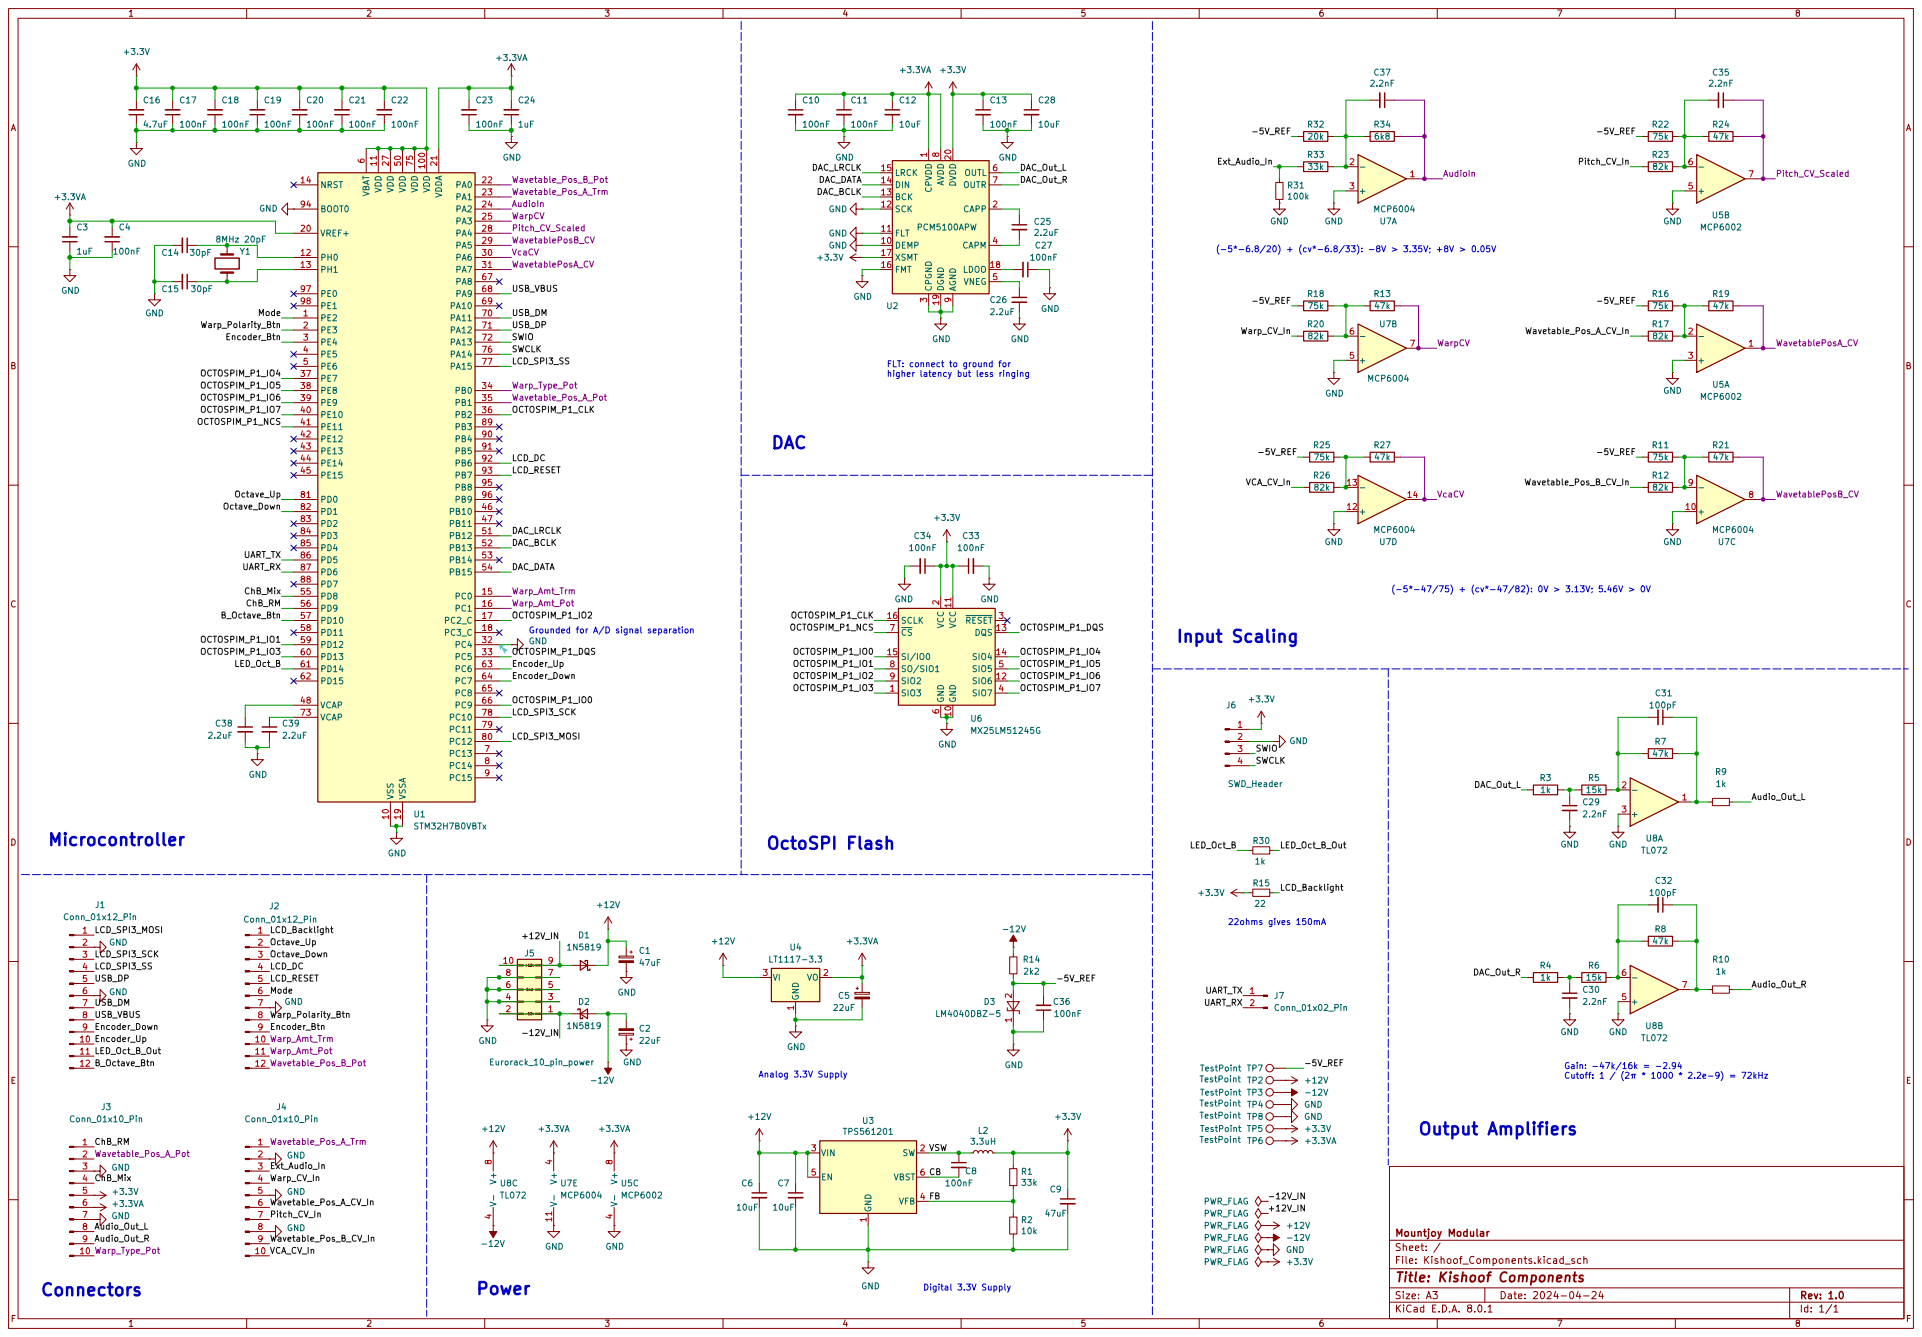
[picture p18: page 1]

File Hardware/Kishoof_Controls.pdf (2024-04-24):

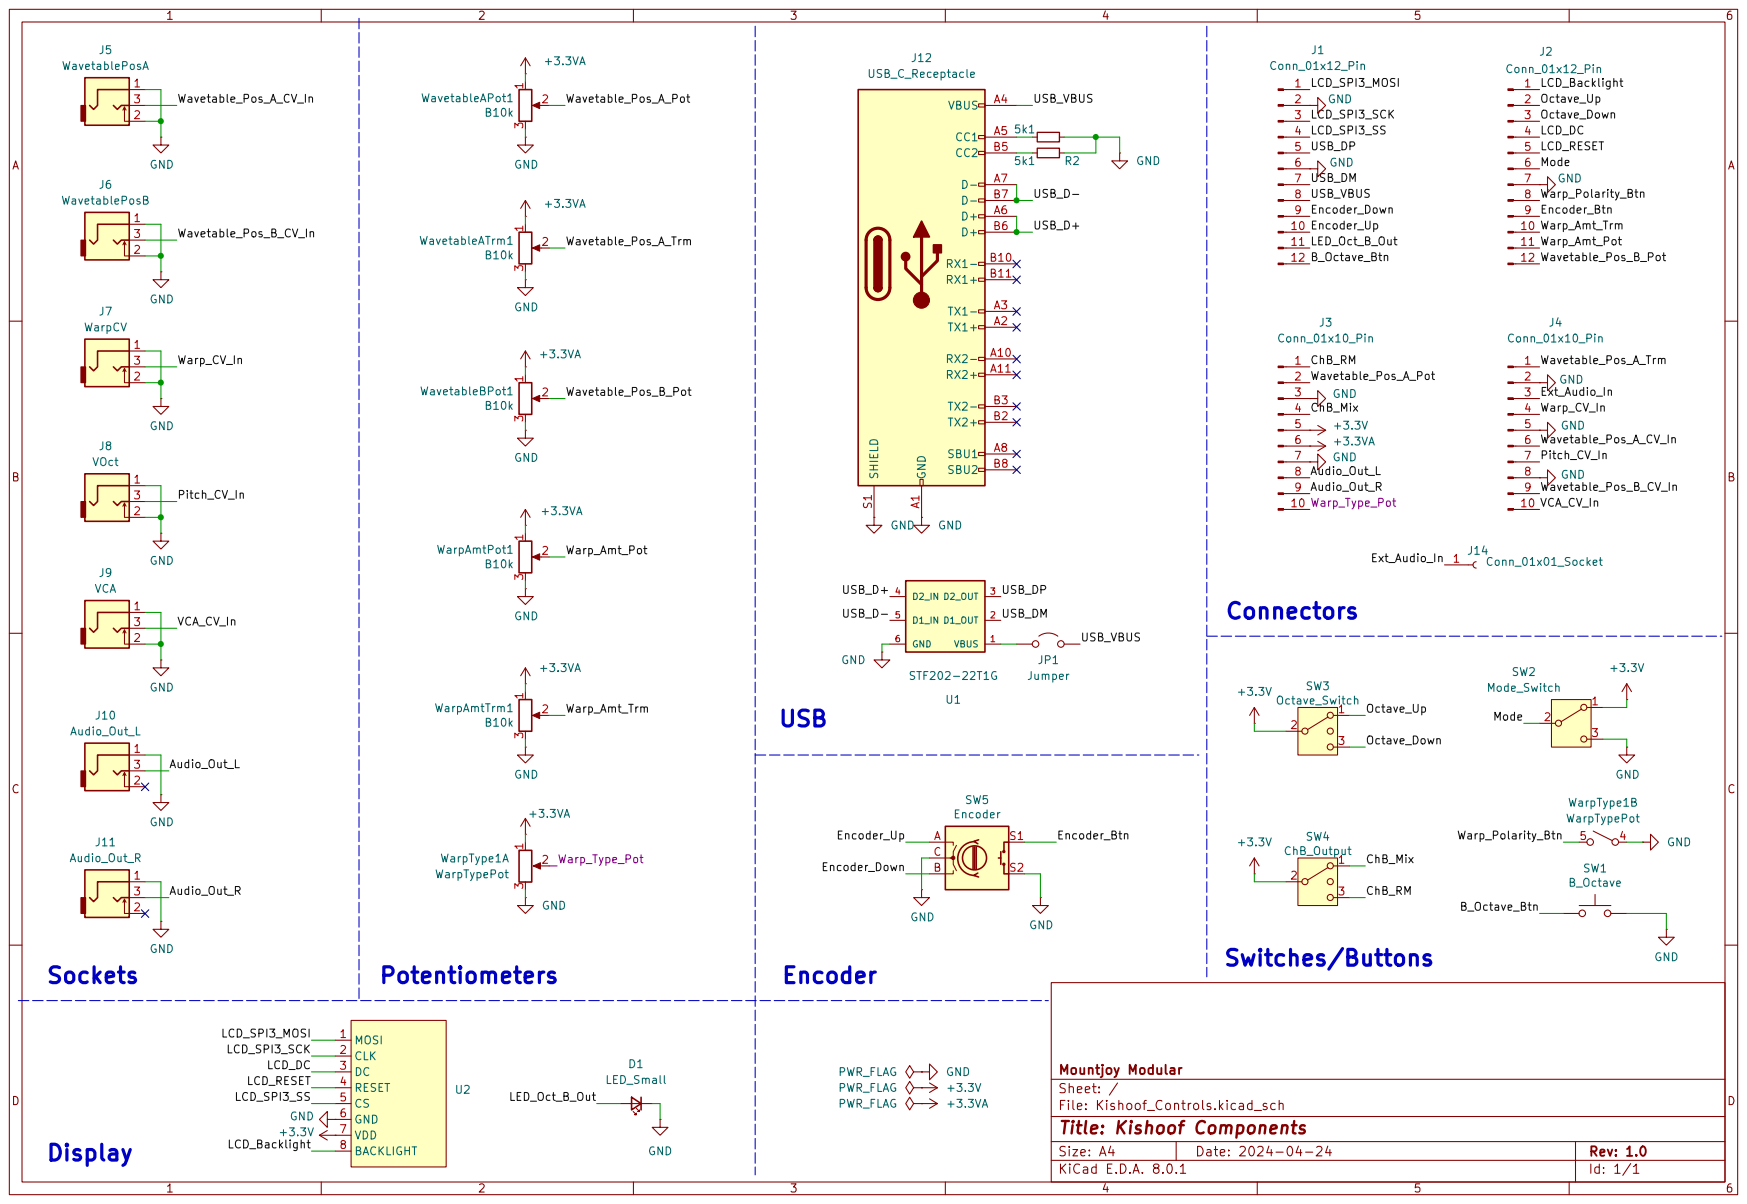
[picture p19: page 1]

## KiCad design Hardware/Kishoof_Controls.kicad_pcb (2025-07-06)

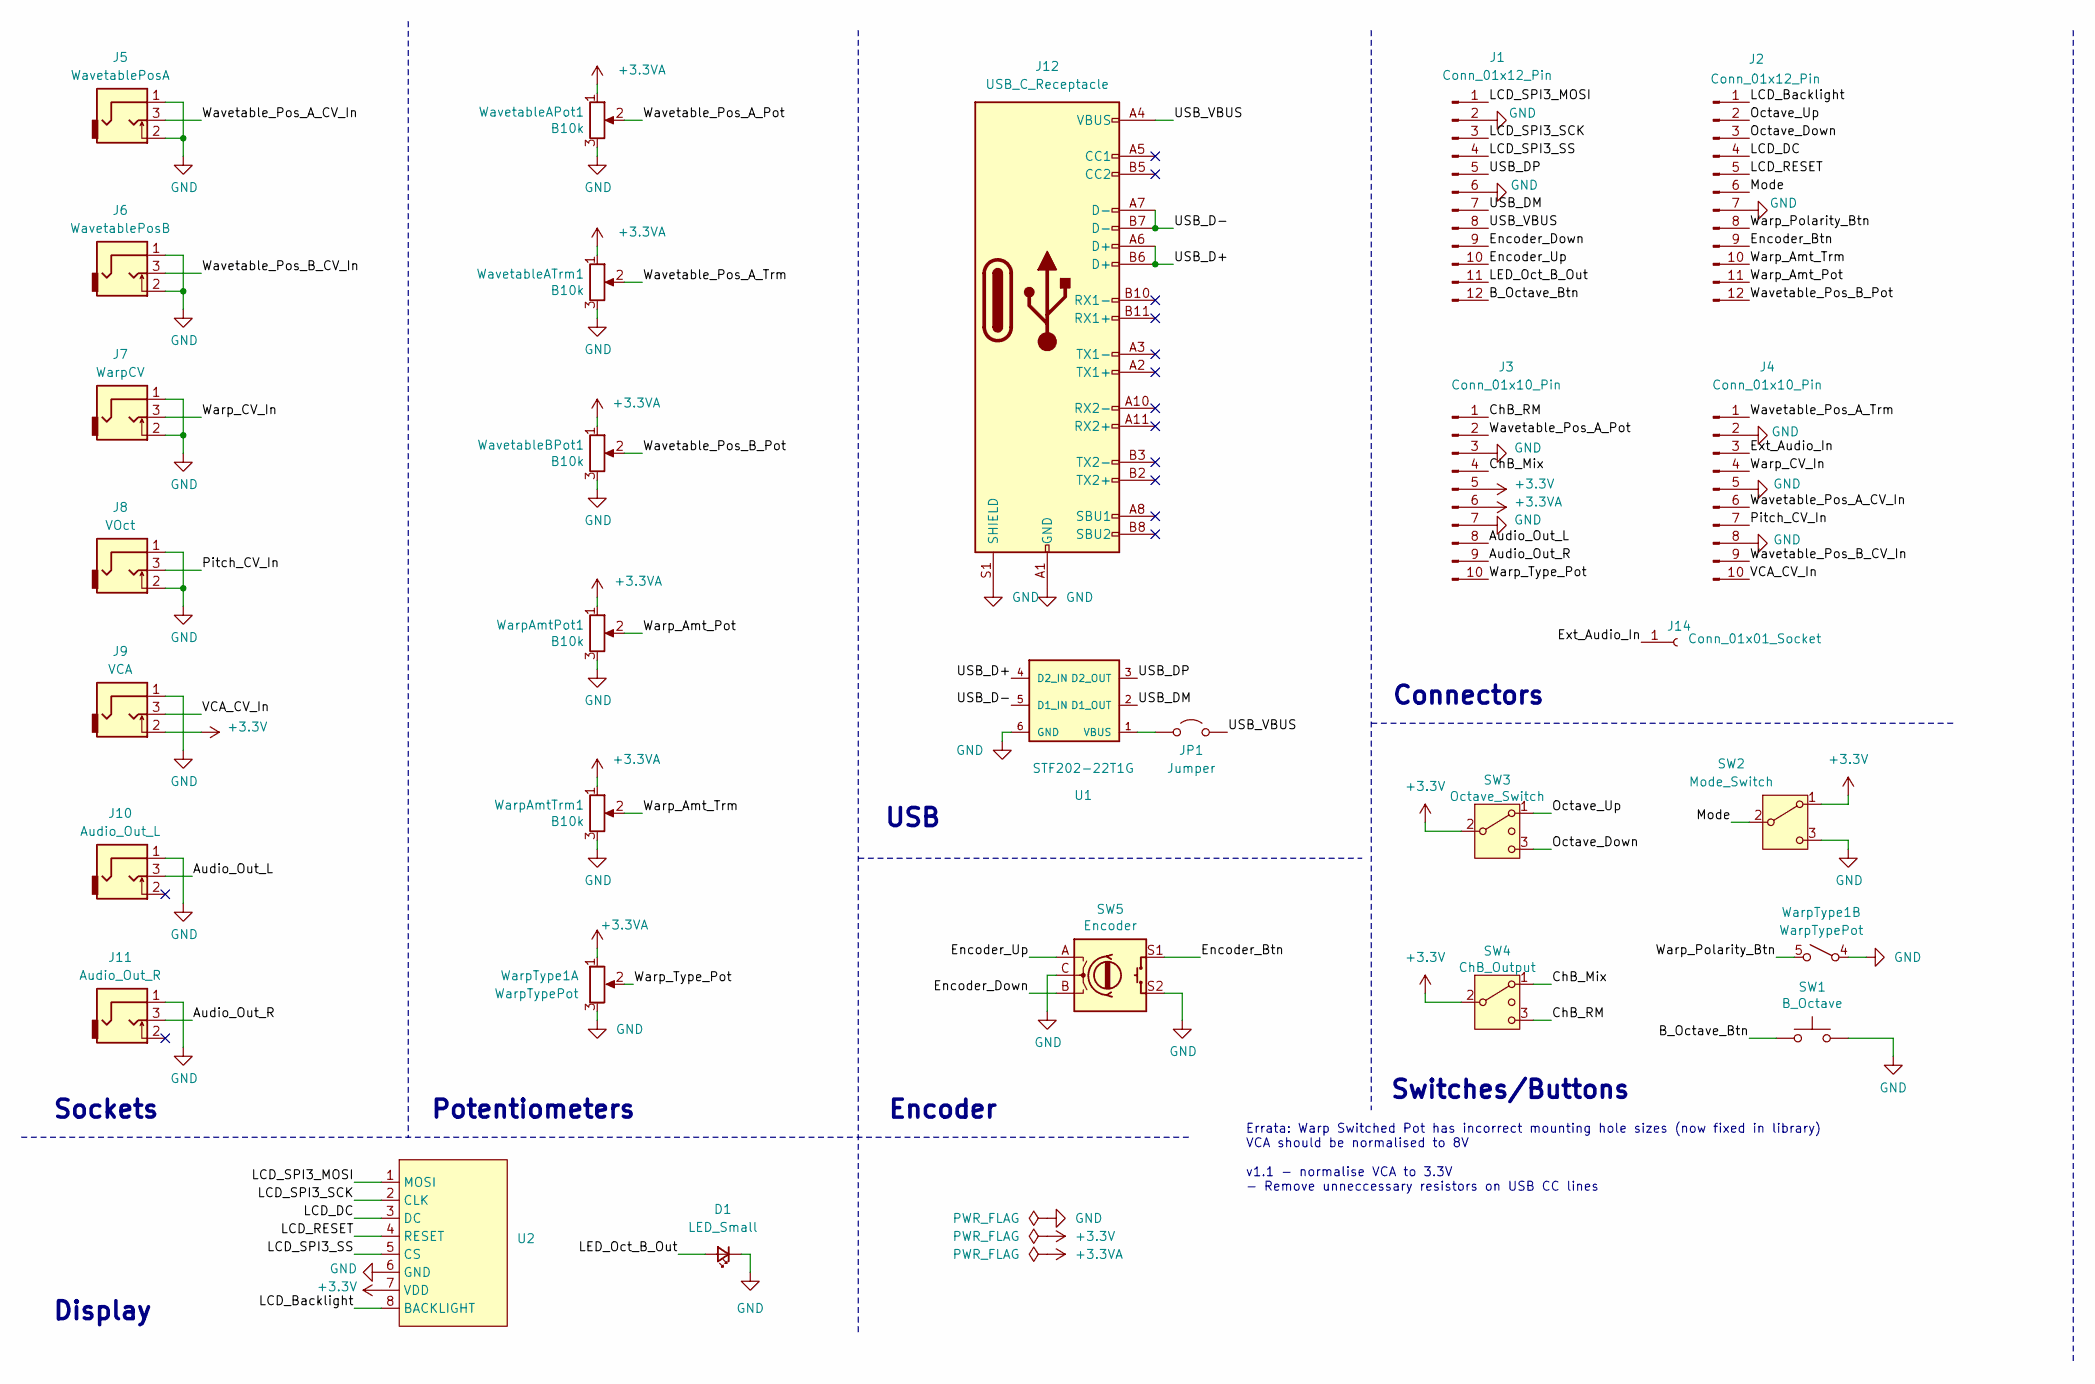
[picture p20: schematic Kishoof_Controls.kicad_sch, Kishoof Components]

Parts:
D1: LED_Small; LED_D3.0mm_FlatTop
J1, J2: Conn_01x12_Pin; PinSocket_1x12_P2.54mm_Vertical
J3, J4: Conn_01x10_Pin; PinSocket_1x10_P2.54mm_Vertical
J5: WavetablePosA; THONKICONN_hole
J6: WavetablePosB; THONKICONN_hole
J7: WarpCV; THONKICONN_hole
J8: VOct; THONKICONN_hole
J9: VCA; THONKICONN_hole
J10: Audio_Out_L; THONKICONN_hole
J11: Audio_Out_R; THONKICONN_hole
J12: USB_C_Receptacle; USB_C_Receptacle_Amphenol_12401951E412A
J14: Conn_01x01_Socket; PinHeader_1x01_P2.54mm_Vertical
JP1: Jumper; SolderJumper-2_P1.3mm_Open_RoundedPad1.0x1.5mm
SW1: B_Octave; SW_PUSH_6mm_aligned
SW2: Mode_Switch; SPDT_Miniature
SW3: Octave_Switch; SP3T_Mini_Switch
SW4: ChB_Output; SP3T_Mini_Switch
SW5: Encoder
U1: STF202-22T1G
U2: LCD_Riser
WarpAmtPot1: B10k; Alpha_9mm_Potentiometer_Aligned
WarpAmtTrm1: B10k; Alpha_9mm_Potentiometer_Aligned
WarpType1: WarpTypePot; Bourns_Switch_Potentiometer
WavetableAPot1: B10k; Alpha_9mm_Potentiometer_Aligned
WavetableATrm1: B10k; Alpha_9mm_Potentiometer_Aligned
WavetableBPot1: B10k; Alpha_9mm_Potentiometer_Aligned

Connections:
+3.3V: J3.5, J9.2, SW2.1 (A), SW3.2 (3), SW4.2 (3), U2.7 (VDD)
+3.3VA: J3.6, WarpAmtPot1.1, WarpAmtTrm1.1, WarpType1.1, WavetableAPot1.1, WavetableATrm1.1, WavetableBPot1.1
/Audio_Out_L: J3.8, J10.3
/Audio_Out_R: J3.9, J11.3
/B_Octave_Btn: J1.12, SW1.1
/ChB_Mix: J3.4, SW4.1
/ChB_RM: J3.1, SW4.3 (4)
/Encoder_Btn: J2.9, SW5.S1
/Encoder_Down: J1.9, SW5.B
/Encoder_Up: J1.10, SW5.A
/Ext_Audio_In: J4.3, J14.1
/LCD_Backlight: J2.1, U2.8 (BACKLIGHT)
/LCD_DC: J2.4, U2.3 (DC)
/LCD_RESET: J2.5, U2.4 (RESET)
/LCD_SPI3_MOSI: J1.1, U2.1 (MOSI)
/LCD_SPI3_SCK: J1.3, U2.2 (CLK)
/LCD_SPI3_SS: J1.4, U2.5 (CS)
/LED_Oct_B_Out: D1.2 (A), J1.11
/Mode: J2.6, SW2.2 (B)
/Octave_Down: J2.3, SW3.3 (4)
/Octave_Up: J2.2, SW3.1
/Pitch_CV_In: J4.7, J8.3
/USB_D+: J12.A6 (D+), J12.B6 (D+), U1.4 (D2_IN)
/USB_D-: J12.A7 (D-), J12.B7 (D-), U1.5 (D1_IN)
/USB_DM: J1.7, U1.2 (D1_OUT)
/USB_DP: J1.5, U1.3 (D2_OUT)
/USB_VBUS: J1.8, J12.A4 (VBUS), J12.A9 (VBUS), J12.B4 (VBUS), J12.B9 (VBUS), JP1.2 (B)
/VCA_CV_In: J4.10, J9.3
/Warp_Amt_Pot: J2.11, WarpAmtPot1.2
/Warp_Amt_Trm: J2.10, WarpAmtTrm1.2
/Warp_CV_In: J4.4, J7.3
/Warp_Polarity_Btn: J2.8, WarpType1.5 (2)
/Warp_Type_Pot: J3.10, WarpType1.2
/Wavetable_Pos_A_CV_In: J4.6, J5.3
/Wavetable_Pos_A_Pot: J3.2, WavetableAPot1.2
/Wavetable_Pos_A_Trm: J4.1, WavetableATrm1.2
/Wavetable_Pos_B_CV_In: J4.9, J6.3
/Wavetable_Pos_B_Pot: J2.12, WavetableBPot1.2
GND: D1.1 (K), J1.2, J1.6, J2.7, J3.3, J3.7, J4.2, J4.5, J4.8, J5.1, J5.2, J6.1, J6.2, J7.1, J7.2, J8.1, J8.2, J9.1, J10.1, J11.1, J12.A1 (GND), J12.A12 (GND), J12.B1 (GND), J12.B12 (GND), J12.S1 (SHIELD), SW1.2, SW2.3 (C), SW5.C, SW5.S2, U1.6 (GND), U2.6 (GND), WarpAmtPot1.3, WarpAmtTrm1.3, WarpType1.3, WarpType1.4 (1), WavetableAPot1.3, WavetableATrm1.3, WavetableBPot1.3
unnamed: JP1.1 (A), U1.1 (VBUS)

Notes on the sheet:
Encoder
Errata: Warp Switched Pot has incorrect mounting hole sizes (now fixed in library) VCA should be normalised to 8V v1.1 - normalise VCA to 3.3V - Remove unneccessary resistors on USB CC lines
Sockets
Connectors
Potentiometers
Switches/Buttons
Display
USB

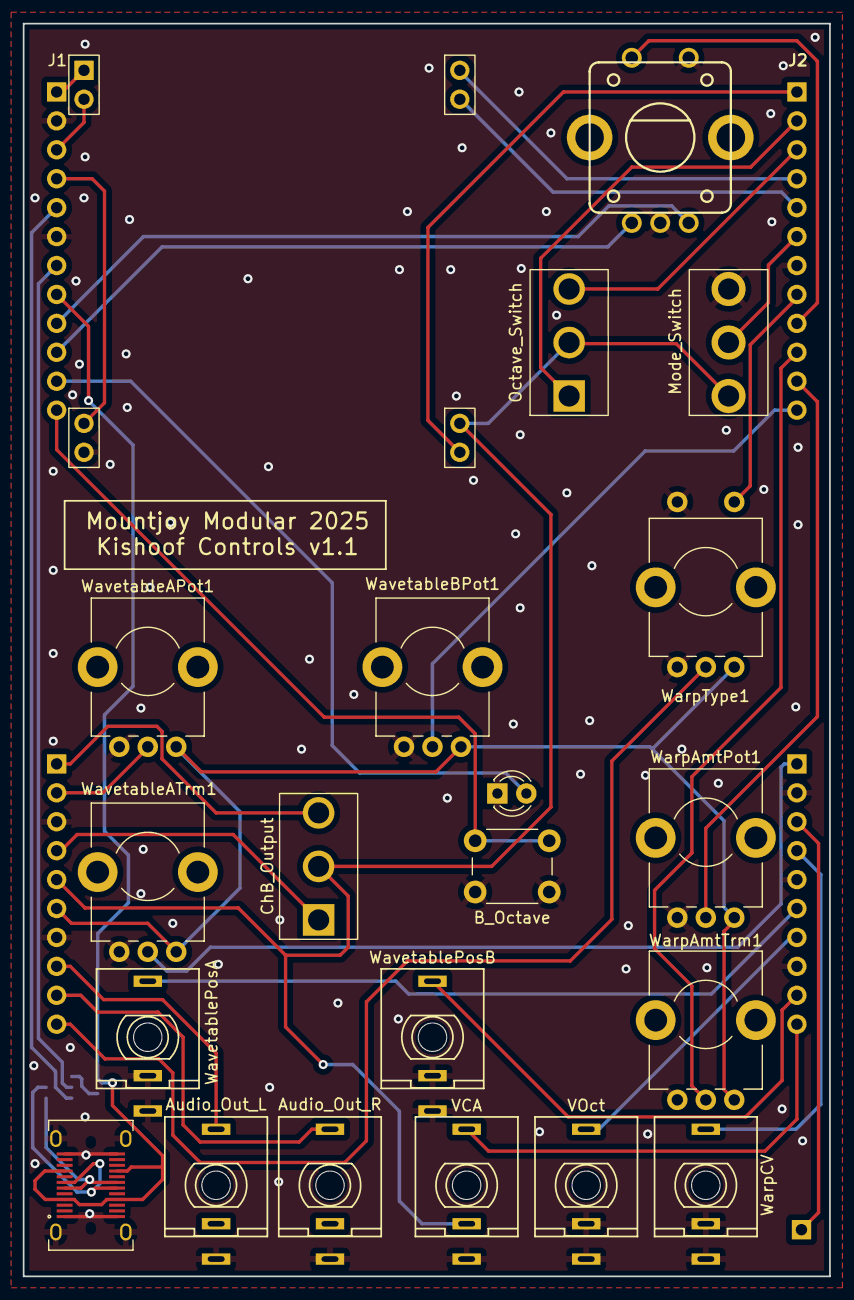
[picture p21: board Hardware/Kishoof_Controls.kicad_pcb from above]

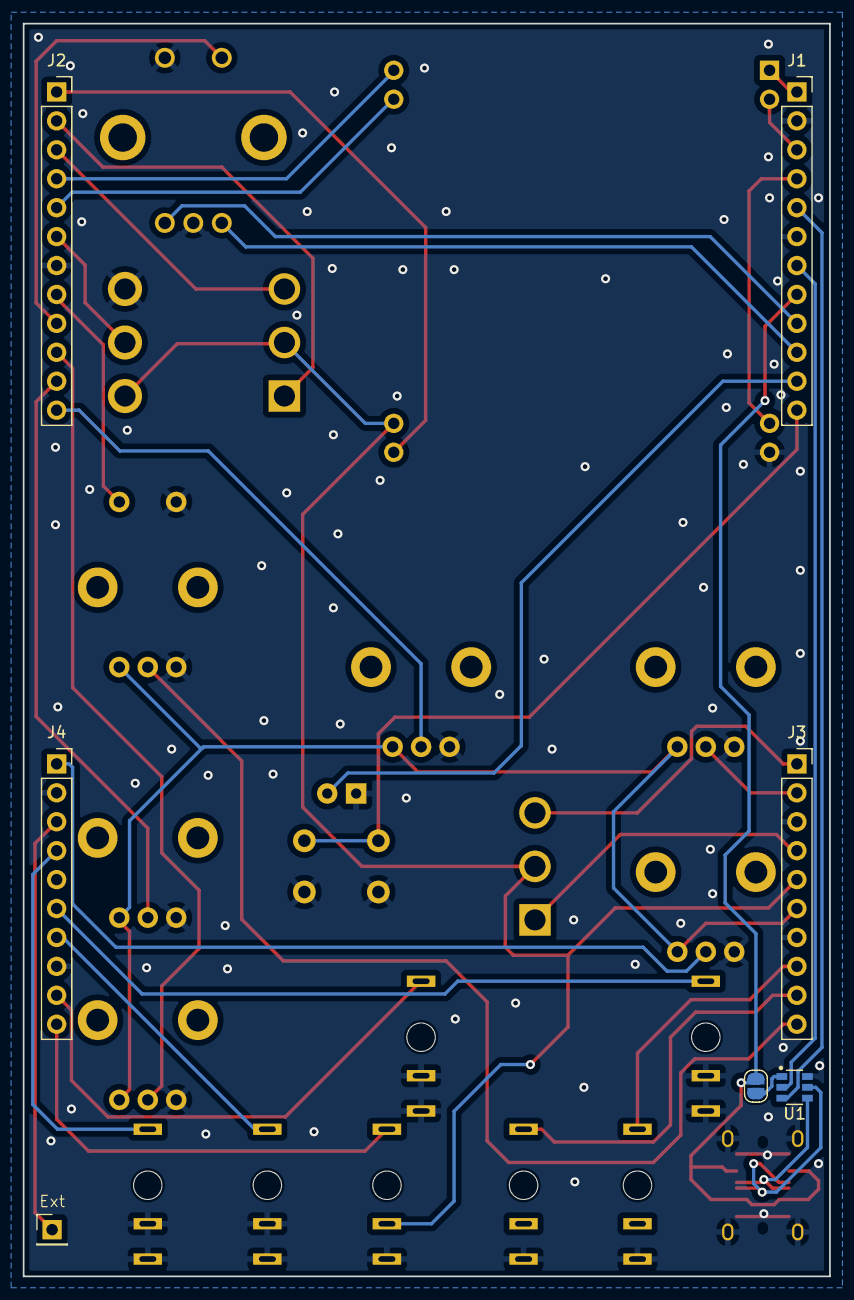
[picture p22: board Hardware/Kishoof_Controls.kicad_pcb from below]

Board: 2 copper layers, 70.8 x 110.0 mm, 28 parts (7 on the bottom side), 40 nets.

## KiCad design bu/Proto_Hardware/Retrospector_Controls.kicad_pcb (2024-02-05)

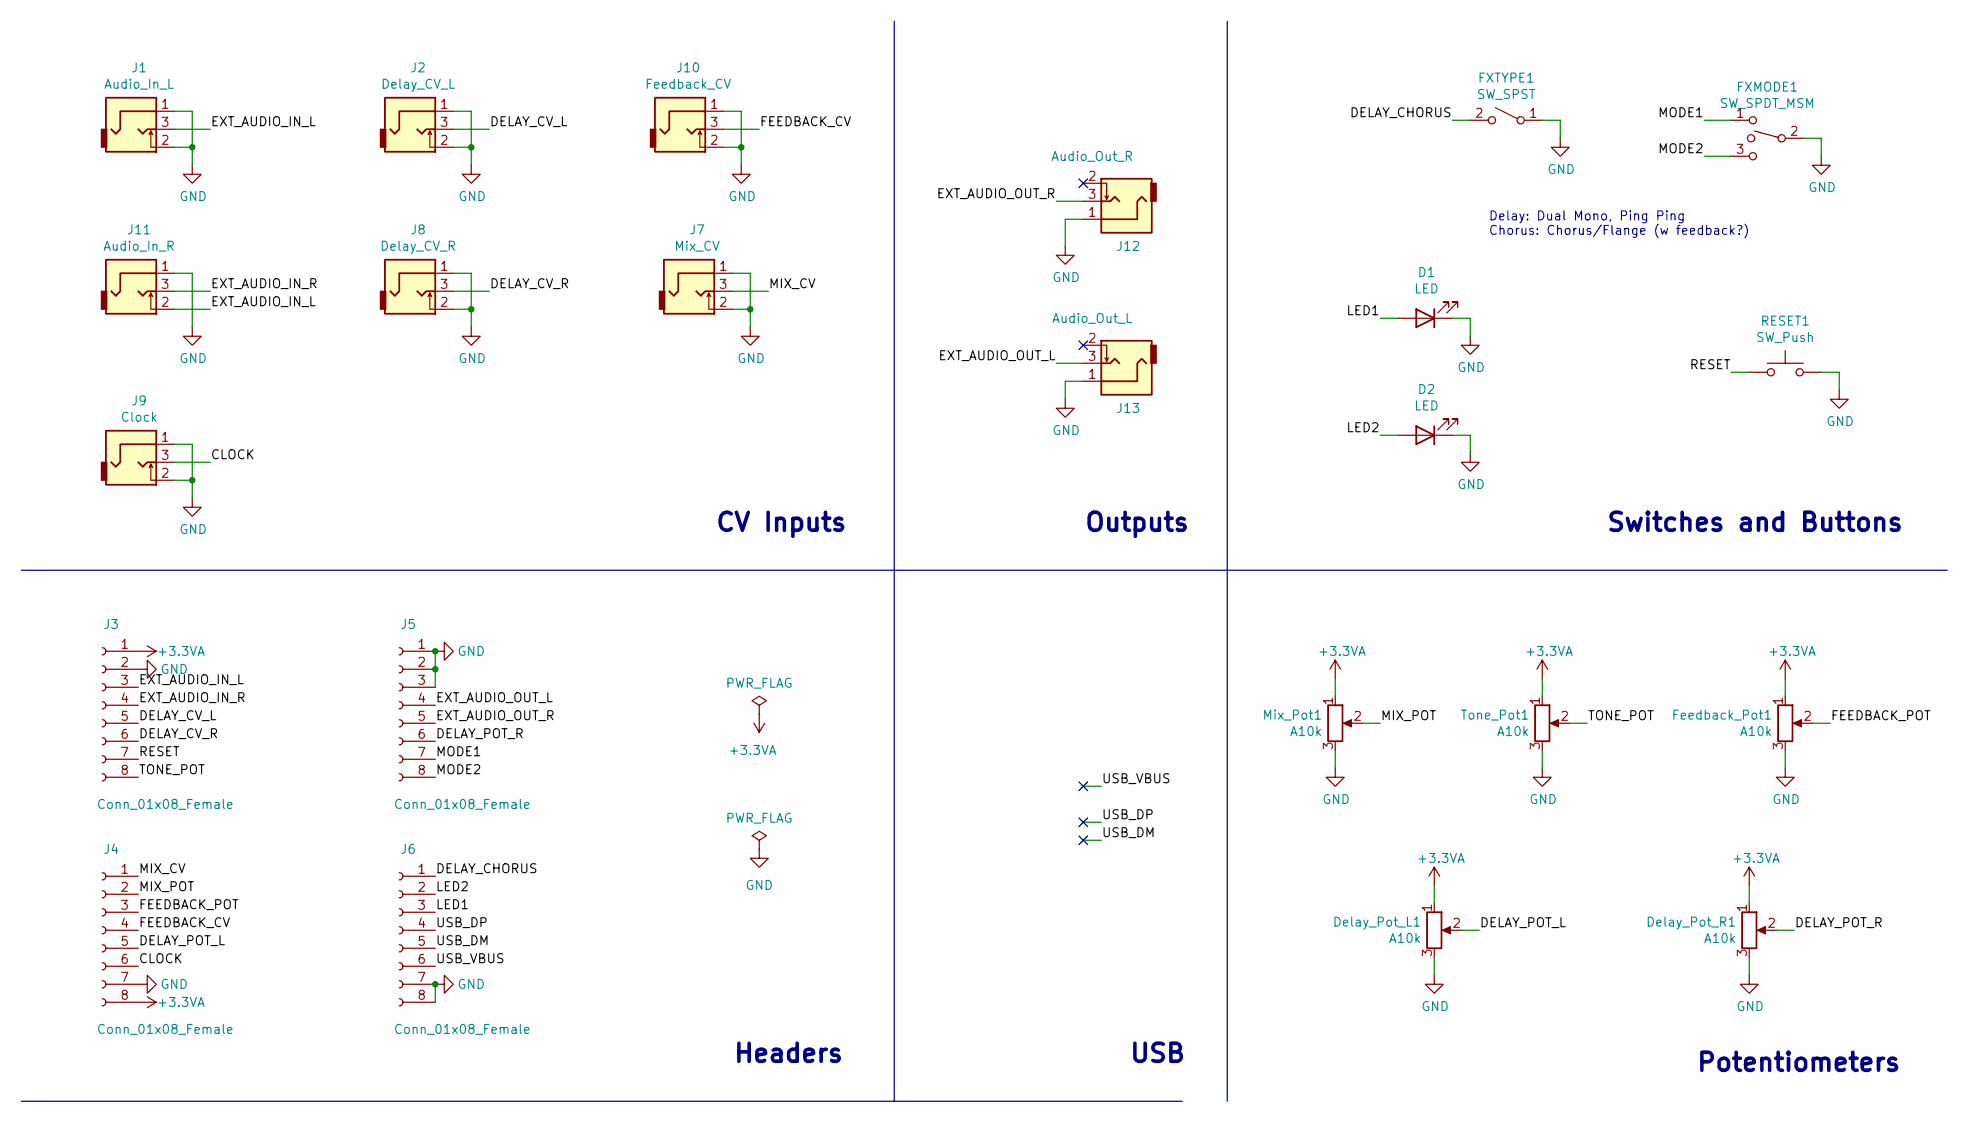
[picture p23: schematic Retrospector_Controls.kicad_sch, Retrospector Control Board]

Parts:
D1, D2: LED; LED_D3.0mm
Delay_Pot_L1: A10k; Alpha_9mm_Potentiometer
Delay_Pot_R1: A10k; Alpha_9mm_Potentiometer
FXMODE1: SW_SPDT_MSM; SPDTSubMiniature
FXTYPE1: SW_SPST; SPDTSubMiniature
Feedback_Pot1: A10k; Alpha_9mm_Potentiometer
J1: Audio_In_L; THONKICONN_hole
J2: Delay_CV_L; THONKICONN_hole
J3, J4, J5, J6: Conn_01x08_Female; Socket_Strip_Straight_1x08_Pitch2.54mm
J7: Mix_CV; THONKICONN_hole
J8: Delay_CV_R; THONKICONN_hole
J9: Clock; THONKICONN_hole
J10: Feedback_CV; THONKICONN_hole
J11: Audio_In_R; THONKICONN_hole
J12: Audio_Out_R; THONKICONN_hole
J13: Audio_Out_L; THONKICONN_hole
Mix_Pot1: A10k; Alpha_9mm_Potentiometer
RESET1: SW_Push; SW_PUSH_6mm
Tone_Pot1: A10k; Alpha_9mm_Potentiometer

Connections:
+3.3VA: Delay_Pot_L1.1, Delay_Pot_R1.1, Feedback_Pot1.1, J3.1, J4.8, Mix_Pot1.1, Tone_Pot1.1
/CLOCK: J4.6, J9.3
/DELAY_CHORUS: FXTYPE1.2 (B), J6.1
/DELAY_CV_L: J2.3, J3.5
/DELAY_CV_R: J3.6, J8.3
/DELAY_POT_L: Delay_Pot_L1.2, J4.5
/DELAY_POT_R: Delay_Pot_R1.2, J5.6
/EXT_AUDIO_IN_L: J1.3, J3.3, J11.2
/EXT_AUDIO_IN_R: J3.4, J11.3
/EXT_AUDIO_OUT_L: J5.4, J13.3
/EXT_AUDIO_OUT_R: J5.5, J12.3
/FEEDBACK_CV: J4.4, J10.3
/FEEDBACK_POT: Feedback_Pot1.2, J4.3
/LED1: D1.2 (A), J6.3
/LED2: D2.2 (A), J6.2
/MIX_CV: J4.1, J7.3
/MIX_POT: J4.2, Mix_Pot1.2
/MODE1: FXMODE1.1, J5.7
/MODE2: FXMODE1.3, J5.8
/RESET: J3.7, RESET1.1
/TONE_POT: J3.8, Tone_Pot1.2
/USB_DM: J6.5
/USB_DP: J6.4
/USB_VBUS: J6.6
GND: D1.1 (K), D2.1 (K), Delay_Pot_L1.3, Delay_Pot_R1.3, FXMODE1.2, FXTYPE1.1 (A), Feedback_Pot1.3, J1.1, J1.2, J2.1, J2.2, J3.2, J4.7, J5.1, J5.2, J5.3, J6.7, J6.8, J7.1, J7.2, J8.1, J8.2, J9.1, J9.2, J10.1, J10.2, J11.1, J12.1, J13.1, Mix_Pot1.3, RESET1.2, Tone_Pot1.3

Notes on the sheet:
Potentiometers
Switches and Buttons
CV Inputs
Delay: Dual Mono, Ping Ping Chorus: Chorus/Flange (w feedback?)
Headers
USB
Outputs

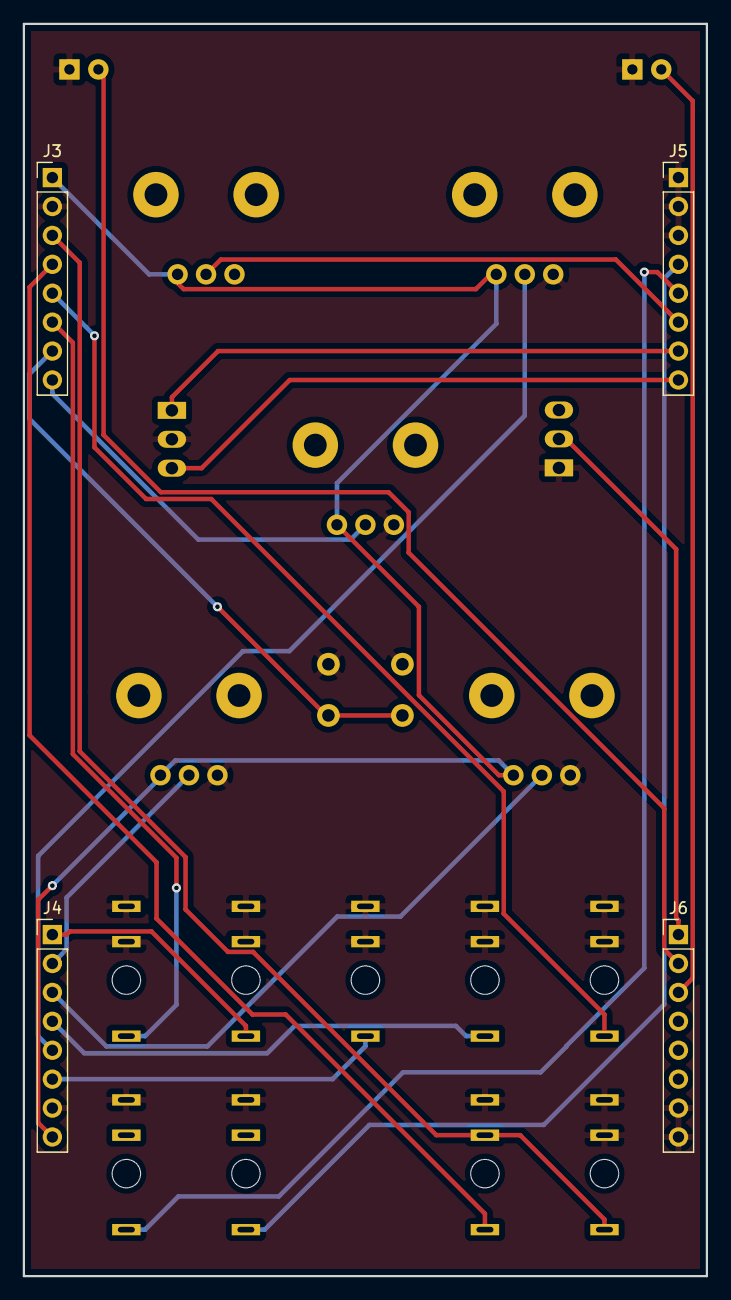
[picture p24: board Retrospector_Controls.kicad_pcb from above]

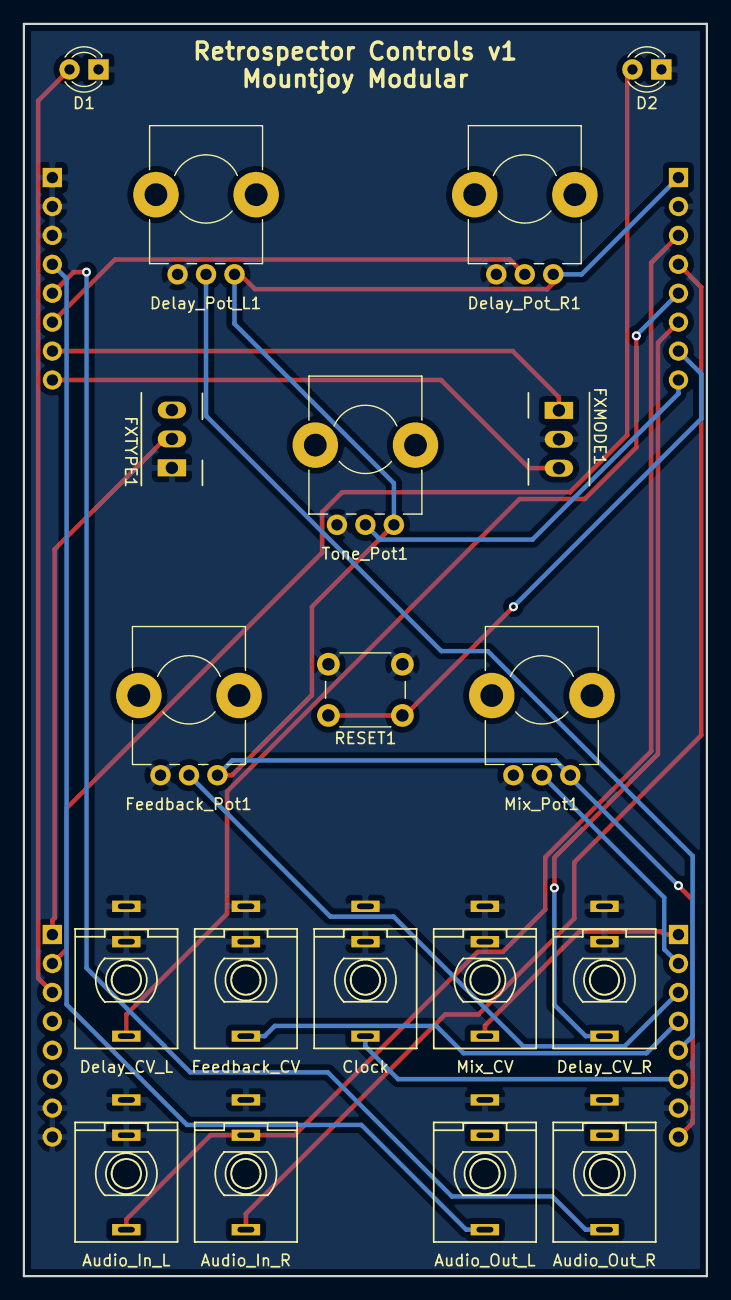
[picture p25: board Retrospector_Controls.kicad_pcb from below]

Board: 2 copper layers, 60.0 x 110.0 mm, 23 parts (19 on the bottom side), 22 nets.

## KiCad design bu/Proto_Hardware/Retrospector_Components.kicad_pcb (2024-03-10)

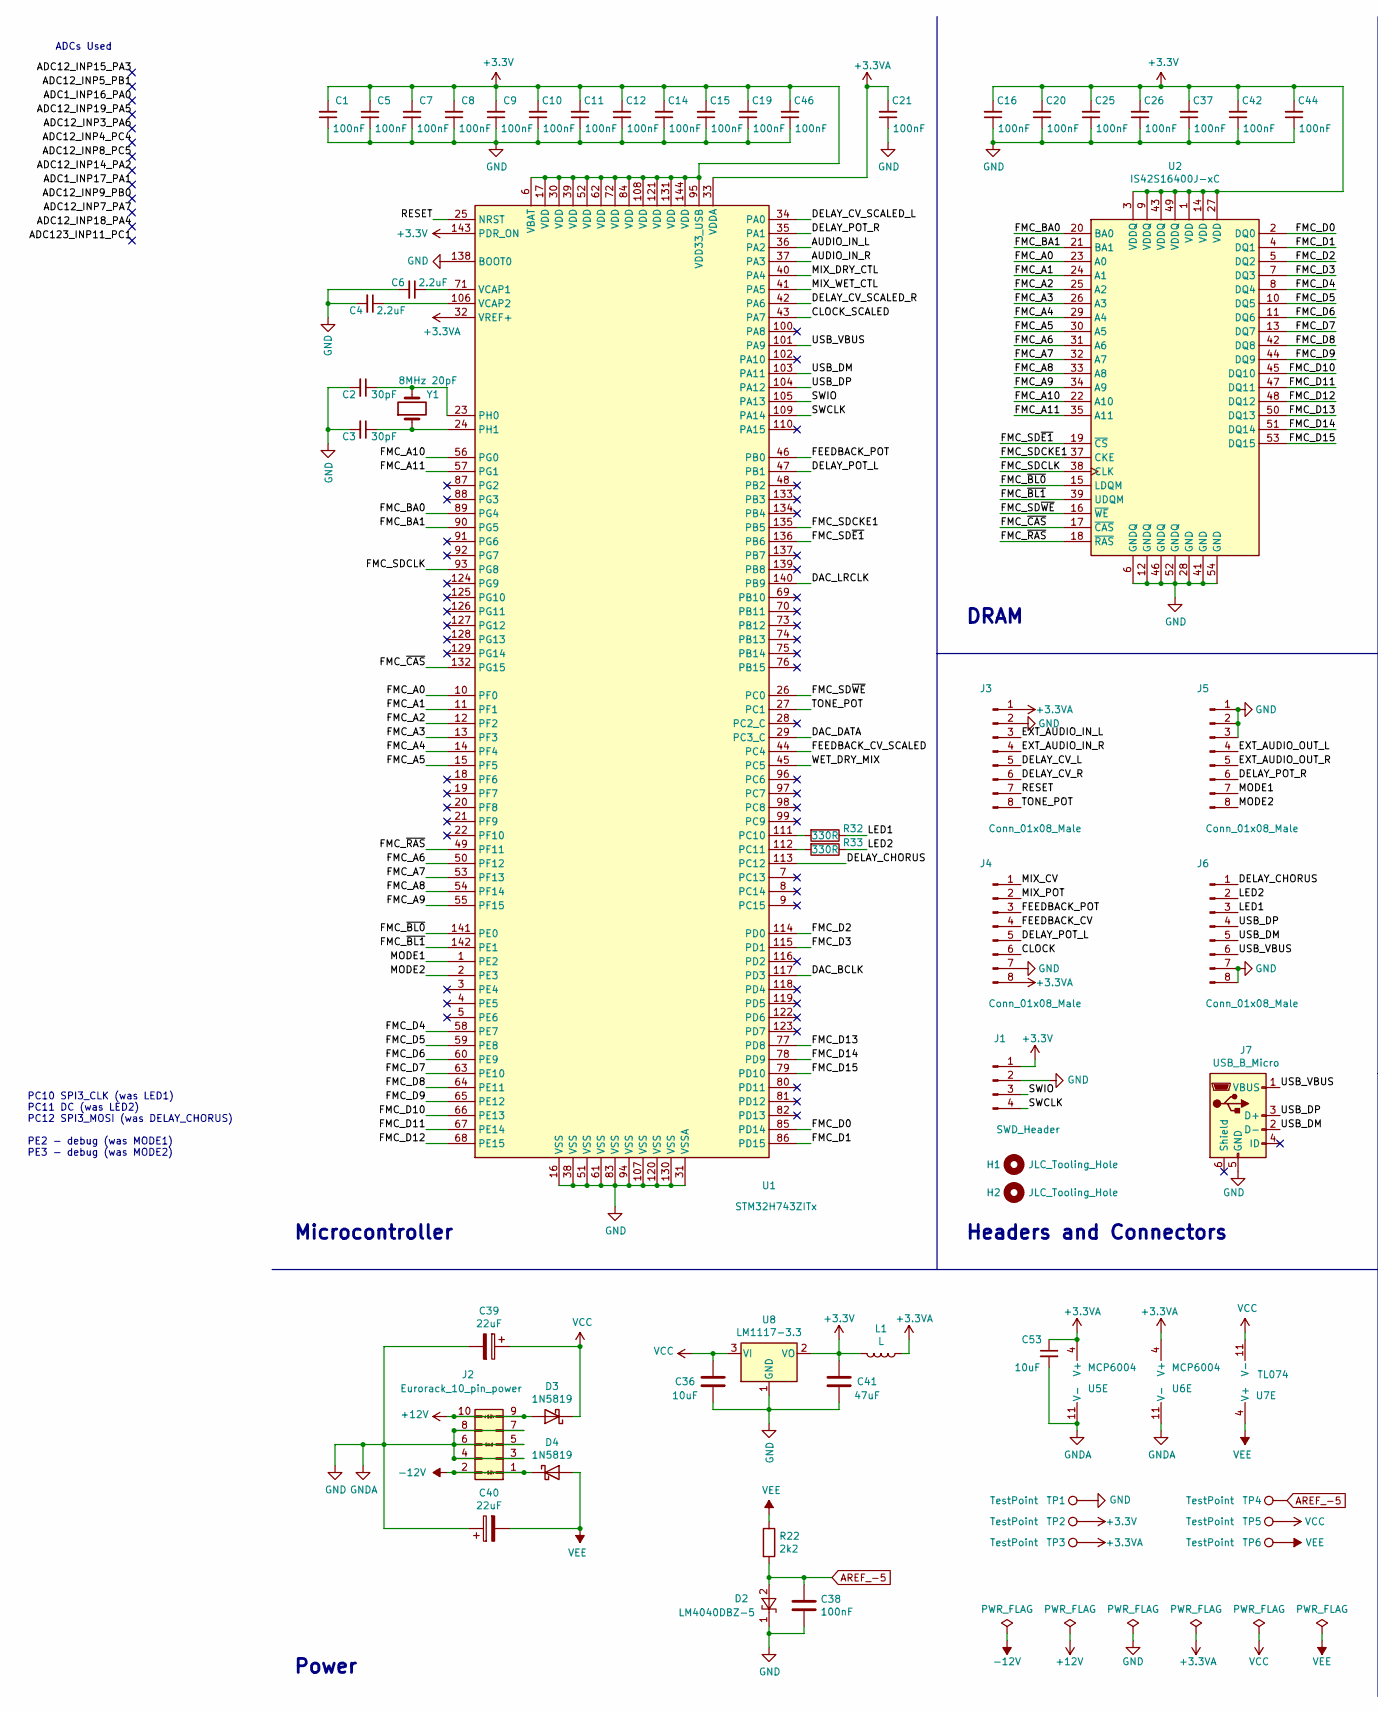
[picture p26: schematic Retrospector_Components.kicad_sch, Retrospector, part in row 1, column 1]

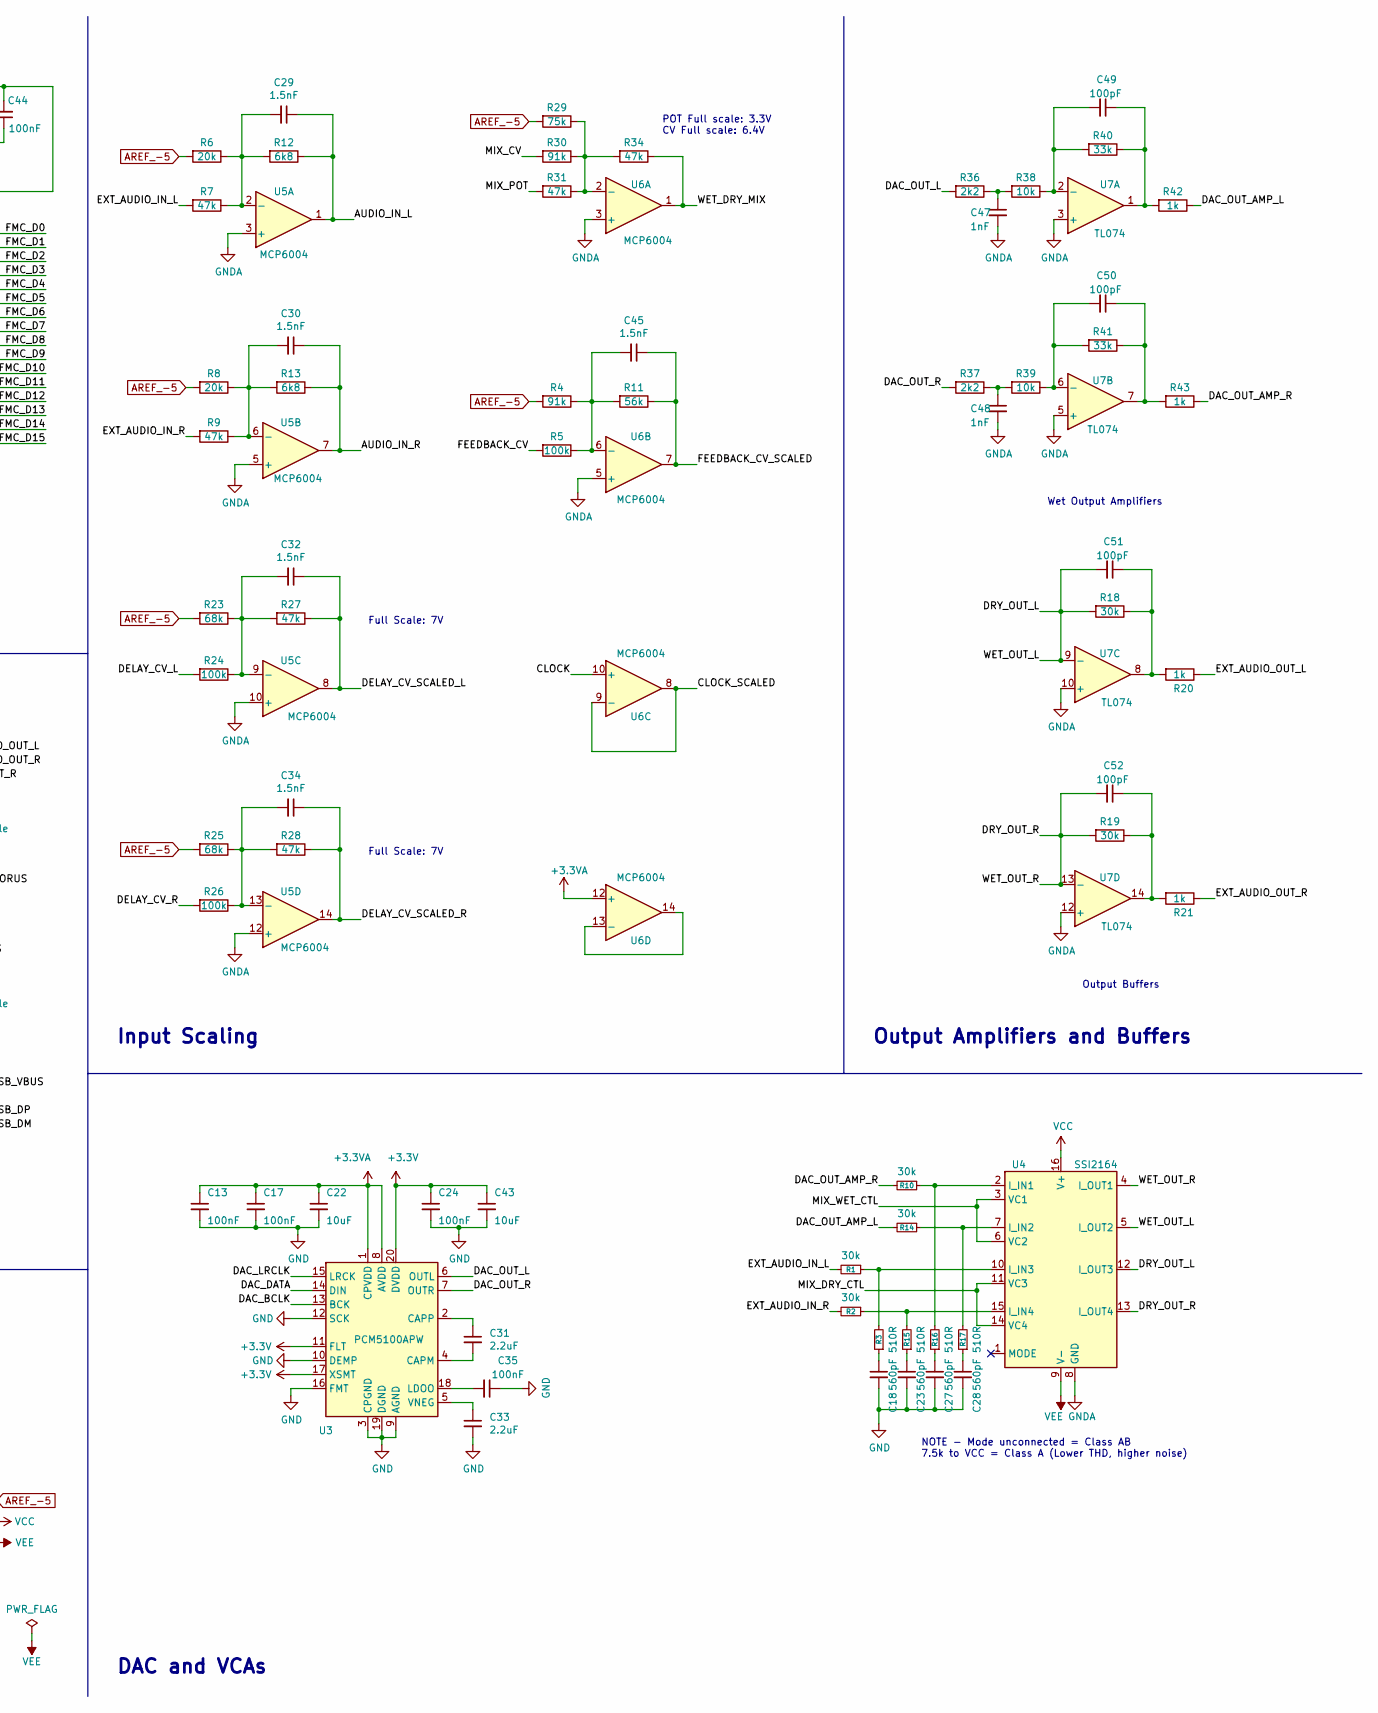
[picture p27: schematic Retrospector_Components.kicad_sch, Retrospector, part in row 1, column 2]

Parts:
C1, C5, C7, C8, C9, C10, C11, C12, C13, C14, C15, C16, C17, C19, C20, C21, C24, C25, C26, C35, C37, C38, C42, C44, C46: 100nF; C_0603_HandSoldering; Part_Number C14663
C2, C3: 30pF; C_0603_HandSoldering; Part_Number C22397
C4, C6, C31, C33: 2.2uF; C_0603_HandSoldering; Part_Number C23630
C18, C23, C27, C28: 560pF; C_0603_HandSoldering; Part_Number C84721
C22, C43, C53: 10uF; C_0805; Part_Number C15850
C29, C30, C32, C34, C45: 1.5nF; C_0603_HandSoldering; Part_Number C1595
C36: 10uF; CP_Elec_3x5.3; Part_Number C249452
C39, C40: 22uF; CP_Elec_6.3x5.3; Part_Number C249771
C41: 47uF; CP_Elec_6.3x7.7; Part_Number C108053
C47, C48: 1nF; C_0805; Part_Number C46653
C49, C50, C51, C52: 100pF; C_0805; Part_Number C1790
D2: LM4040DBZ-5; SOT-23; Part_Number C69316
D3, D4: 1N5819; D_SOD-123; Part_Number C169540
H1, H2: JLC_Tooling_Hole; JLC_SMT_Tooling_Hole
J1: SWD_Header; SWD_header
J2: Eurorack_10_pin_power; Eurorack_10_pin_header
J3, J4, J5, J6: Conn_01x08_Male; Pin_Header_Straight_1x08_Pitch2.54mm
J7: USB_B_Micro; USB_Micro-B_Amphenol
L1: L; L_0805_HandSoldering; Part_Number C1046
R1, R2, R10, R14, R18, R19: 30k; R_0603_HandSoldering; Part_Number C22984
R3, R15, R16, R17: 510R; R_0603_HandSoldering; Part_Number C23193
R4, R30: 91k; R_0603_HandSoldering; Part_Number C23265
R5, R24, R26: 100k; R_0603_HandSoldering; Part_Number C25803
R6, R8: 20k; R_0603_HandSoldering; Part_Number C4184
R7, R9, R27, R28, R31, R34: 47k; R_0603_HandSoldering; Part_Number C25819
R11: 56k; R_0603_HandSoldering; Part_Number C23206
R12, R13: 6k8; R_0603_HandSoldering; Part_Number C23212
R20, R21, R42, R43: 1k; R_0603_HandSoldering; Part_Number C21190
R22, R36, R37: 2k2; R_0603_HandSoldering; Part_Number C4190
R23, R25: 68k; R_0603_HandSoldering; Part_Number C23231
R29: 75k; R_0603_HandSoldering; Part_Number C23242
R32, R33: 330R; R_0603_HandSoldering; Part_Number C23138
R38, R39: 10k; R_0603_HandSoldering; Part_Number C25804
R40, R41: 33k; R_0603_HandSoldering; Part_Number C4216
TP1, TP2, TP3, TP4, TP5, TP6: TestPoint; Test_Point_Keystone_5005-5009_Compact
U1: STM32H743ZITx; LQFP-144_20x20mm_P0.5mm; Part_Number C114408
U2: IS42S16400J-xC; TSOP-II-54_22.2x10.16mm_P0.8mm; Part_Number C69411
U3: PCM5100APW; SSOP-20_4.4x6.5mm_Pitch0.65mm_Round_Pads; Part_Number C131154
U4: SSI2164; SOIC-16_3.9x9.9mm_Pitch1.27mm
U5, U6: MCP6004; SOIC-14_N; Part_Number C7378
U7: TL074; SOIC-14_N; Part_Number C6964
U8: LM1117-3.3; SOT-223; Part_Number C6186
Y1: 8MHz 20pF; Crystal_SMD_5032-2pin_5.0x3.2mm_HandSoldering; Part_Number C115962

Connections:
+3.3VA: C13.1, C17.1, C21.2, C22.1, C53.1, J3.1, J4.8, L1.1, TP3.1, U1.32 (VREF+), U1.33 (VDDA), U3.1 (CPVDD), U3.8 (AVDD), U5.4 (V+), U6.4 (V+), U6.12 (+)
+3V3: C1.2, C5.2, C7.2, C8.2, C9.2, C10.2, C11.2, C12.2, C14.2, C15.2, C16.2, C19.2, C20.2, C24.1, C25.2, C26.2, C37.2, C41.1, C42.2, C43.1, C44.2, C46.2, J1.1, L1.2, TP2.1, U1.6 (VBAT), U1.17 (VDD), U1.30 (VDD), U1.39 (VDD), U1.52 (VDD), U1.62 (VDD), U1.72 (VDD), U1.84 (VDD), U1.95 (VDD33_USB), U1.108 (VDD), U1.121 (VDD), U1.131 (VDD), U1.143 (PDR_ON), U1.144 (VDD), U2.1 (VDD), U2.3 (VDDQ), U2.9 (VDDQ), U2.14 (VDD), U2.27 (VDD), U2.43 (VDDQ), U2.49 (VDDQ), U3.11 (FLT), U3.17 (XSMT), U3.20 (DVDD), U8.2 (VO)
+12V: D3.2 (A), J2.9, J2.10
-12V: D4.1 (K), J2.1, J2.2
/AUDIO_IN_L: C29.1, R12.1, U1.36 (PA2), U5.1
/AUDIO_IN_R: C30.1, R13.1, U1.37 (PA3), U5.7
/CLOCK: J4.6, U6.10 (+)
/CLOCK_SCALED: U1.43 (PA7), U6.8, U6.9 (-)
/DAC_BCLK: U1.117 (PD3), U3.13 (BCK)
/DAC_DATA: U1.29 (PC3_C), U3.14 (DIN)
/DAC_LRCLK: U1.140 (PB9), U3.15 (LRCK)
/DAC_OUT_AMP_L: R14.2, R42.1
/DAC_OUT_AMP_R: R10.2, R43.1
/DAC_OUT_L: R36.2, U3.6 (OUTL)
/DAC_OUT_R: R37.2, U3.7 (OUTR)
/DELAY_CHORUS: J6.1, U1.113 (PC12)
/DELAY_CV_L: J3.5, R24.2
/DELAY_CV_R: J3.6, R26.2
/DELAY_CV_SCALED_L: C32.1, R27.1, U1.34 (PA0), U5.8
/DELAY_CV_SCALED_R: C34.1, R28.1, U1.42 (PA6), U5.14
/DELAY_POT_L: J4.5, U1.47 (PB1)
/DELAY_POT_R: J5.6, U1.35 (PA1)
/DRY_OUT_L: C51.2, R18.2, U4.5 (I_OUT2), U4.12 (I_OUT3), U7.9 (-)
/DRY_OUT_R: C52.2, R19.2, U4.4 (I_OUT1), U4.13 (I_OUT4), U7.13 (-)
/EXT_AUDIO_IN_L: J3.3, R1.2, R7.2
/EXT_AUDIO_IN_R: J3.4, R2.2, R9.2
/EXT_AUDIO_OUT_L: J5.4, R20.1
/EXT_AUDIO_OUT_R: J5.5, R21.1
/FEEDBACK_CV: J4.4, R5.2
/FEEDBACK_CV_SCALED: C45.1, R11.1, U1.44 (PC4), U6.7
/FEEDBACK_POT: J4.3, U1.46 (PB0)
/FMC_A0: U1.10 (PF0), U2.23 (A0)
/FMC_A1: U1.11 (PF1), U2.24 (A1)
/FMC_A2: U1.12 (PF2), U2.25 (A2)
/FMC_A3: U1.13 (PF3), U2.26 (A3)
/FMC_A4: U1.14 (PF4), U2.29 (A4)
/FMC_A5: U1.15 (PF5), U2.30 (A5)
/FMC_A6: U1.50 (PF12), U2.31 (A6)
/FMC_A7: U1.53 (PF13), U2.32 (A7)
/FMC_A8: U1.54 (PF14), U2.33 (A8)
/FMC_A9: U1.55 (PF15), U2.34 (A9)
/FMC_A10: U1.56 (PG0), U2.22 (A10)
/FMC_A11: U1.57 (PG1), U2.35 (A11)
/FMC_BA0: U1.89 (PG4), U2.20 (BA0)
/FMC_BA1: U1.90 (PG5), U2.21 (BA1)
/FMC_D0: U1.85 (PD14), U2.2 (DQ0)
/FMC_D1: U1.86 (PD15), U2.4 (DQ1)
/FMC_D2: U1.114 (PD0), U2.5 (DQ2)
/FMC_D3: U1.115 (PD1), U2.7 (DQ3)
/FMC_D4: U1.58 (PE7), U2.8 (DQ4)
/FMC_D5: U1.59 (PE8), U2.10 (DQ5)
/FMC_D6: U1.60 (PE9), U2.11 (DQ6)
/FMC_D7: U1.63 (PE10), U2.13 (DQ7)
/FMC_D8: U1.64 (PE11), U2.42 (DQ8)
/FMC_D9: U1.65 (PE12), U2.44 (DQ9)
/FMC_D10: U1.66 (PE13), U2.45 (DQ10)
/FMC_D11: U1.67 (PE14), U2.47 (DQ11)
/FMC_D12: U1.68 (PE15), U2.48 (DQ12)
/FMC_D13: U1.77 (PD8), U2.50 (DQ13)
/FMC_D14: U1.78 (PD9), U2.51 (DQ14)
/FMC_D15: U1.79 (PD10), U2.53 (DQ15)
/FMC_SDCKE1: U1.135 (PB5), U2.37 (CKE)
/FMC_SDCLK: U1.93 (PG8), U2.38 (CLK)
/FMC_SD~E1: U1.136 (PB6), U2.19 (~CS)
/FMC_SD~WE: U1.26 (PC0), U2.16 (~WE)
/FMC_~BL0: U1.141 (PE0), U2.15 (LDQM)
/FMC_~BL1: U1.142 (PE1), U2.39 (UDQM)
/FMC_~CAS: U1.132 (PG15), U2.17 (~CAS)
/FMC_~RAS: U1.49 (PF11), U2.18 (~RAS)
/LED1: J6.3, R32.1
/LED2: J6.2, R33.1
/MIX_CV: J4.1, R30.2
/MIX_DRY_CTL: U1.40 (PA4), U4.11 (VC3), U4.14 (VC4)
/MIX_POT: J4.2, R31.2
/MIX_WET_CTL: U1.41 (PA5), U4.3 (VC1), U4.6 (VC2)
/MODE1: J5.7, U1.1 (PE2)
/MODE2: J5.8, U1.2 (PE3)
/RESET: J3.7, U1.25 (NRST)
/SWCLK: J1.4, U1.109 (PA14)
/SWIO: J1.3, U1.105 (PA13)
/TONE_POT: J3.8, U1.27 (PC1)
/USB_DM: J6.5, J7.2 (D-), U1.103 (PA11)
/USB_DP: J6.4, J7.3 (D+), U1.104 (PA12)
/USB_VBUS: J6.6, J7.1 (VBUS), U1.101 (PA9)
/WET_DRY_MIX: R34.1, U1.45 (PC5), U6.1
AREF_-5: C38.1, D2.2 (A), R4.2, R6.2, R8.2, R22.2, R23.2, R25.2, R29.2, TP4.1
GND: C1.1, C2.2, C3.2, C4.2, C5.1, C6.2, C7.1, C8.1, C9.1, C10.1, C11.1, C12.1, C13.2, C14.1, C15.1, C16.1, C17.2, C18.2, C19.1, C20.1, C21.1, C22.2, C23.2, C24.2, C25.1, C26.1, C27.2, C28.2, C33.2, C35.1, C36.2, C37.1, C38.2, C39.2, C40.1, C41.2, C42.1, C43.2, C44.1, C46.1, C47.2, C48.2, C53.2, D2.1 (K), J1.2, J2.3, J2.4, J2.5, J2.6, J2.7, J2.8, J3.2, J4.7, J5.1, J5.2, J5.3, J6.7, J6.8, J7.5 (GND), TP1.1, U1.16 (VSS), U1.31 (VSSA), U1.38 (VSS), U1.51 (VSS), U1.61 (VSS), U1.83 (VSS), U1.94 (VSS), U1.107 (VSS), U1.120 (VSS), U1.130 (VSS), U1.138 (BOOT0), U2.6 (GNDQ), U2.12 (GNDQ), U2.28 (GND), U2.41 (GND), U2.46 (GNDQ), U2.52 (GNDQ), U2.54 (GND), U3.3 (CPGND), U3.9 (AGND), U3.10 (DEMP), U3.12 (SCK), U3.16 (FMT), U3.19 (DGND), U4.8 (GND), U5.3 (+), U5.5 (+), U5.10 (+), U5.11 (V-), U5.12 (+), U6.3 (+), U6.5 (+), U6.11 (V-), U7.3 (+), U7.5 (+), U7.10 (+), U7.12 (+), U8.1 (GND)
unnamed: C2.1, U1.23 (PH0), Y1.2
unnamed: C3.1, U1.24 (PH1), Y1.1
unnamed: C4.1, U1.106 (VCAP2)
unnamed: C6.1, U1.71 (VCAP1)
unnamed: C18.1, R3.1
unnamed: C23.1, R15.1
unnamed: C27.1, R16.1
unnamed: C28.1, R17.1
unnamed: C29.2, R6.1, R7.1, R12.2, U5.2 (-)
unnamed: C30.2, R8.1, R9.1, R13.2, U5.6 (-)
unnamed: C31.1, U3.2 (CAPP)
unnamed: C31.2, U3.4 (CAPM)
unnamed: C32.2, R23.1, R24.1, R27.2, U5.9 (-)
unnamed: C33.1, U3.5 (VNEG)
unnamed: C34.2, R25.1, R26.1, R28.2, U5.13 (-)
unnamed: C35.2, U3.18 (LDOO)
unnamed: C45.2, R4.1, R5.1, R11.2, U6.6 (-)
unnamed: C47.1, R36.1, R38.2
unnamed: C48.1, R37.1, R39.2
unnamed: C49.1, R40.1, R42.2, U7.1
unnamed: C49.2, R38.1, R40.2, U7.2 (-)
unnamed: C50.1, R41.1, R43.2, U7.7
unnamed: C50.2, R39.1, R41.2, U7.6 (-)
unnamed: C51.1, R18.1, R20.2, U7.8
unnamed: C52.1, R19.1, R21.2, U7.14
unnamed: R1.1, R3.2, U4.10 (I_IN3)
unnamed: R10.1, R16.2, U4.2 (I_IN1)
unnamed: R14.1, R17.2, U4.7 (I_IN2)
unnamed: R2.1, R15.2, U4.15 (I_IN4)
unnamed: R29.1, R30.1, R31.1, R34.2, U6.2 (-)
unnamed: R32.2, U1.111 (PC10)
unnamed: R33.2, U1.112 (PC11)
unnamed: U6.13 (-), U6.14
VCC: C36.1, C39.1, D3.1 (K), TP5.1, U4.16 (V+), U7.11 (V-), U8.3 (VI)
VEE: C40.2, D4.2 (A), R22.1, TP6.1, U4.9 (V-), U7.4 (V+)

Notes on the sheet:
DAC and VCAs
NOTE - Mode unconnected = Class AB 7.5k to VCC = Class A (Lower THD, higher noise)
Input Scaling
Output Buffers
ADCs Used
Full Scale: 7V
Wet Output Amplifiers
Output Amplifiers and Buffers
POT Full scale: 3.3V CV Full scale: 6.4V
Power
PC10 SPI3_CLK (was LED1) PC11 DC (was LED2) PC12 SPI3_MOSI (was DELAY_CHORUS) PE2 - debug (was MODE1) PE3 - debug (was MODE2)
Microcontroller
Headers and Connectors
DRAM

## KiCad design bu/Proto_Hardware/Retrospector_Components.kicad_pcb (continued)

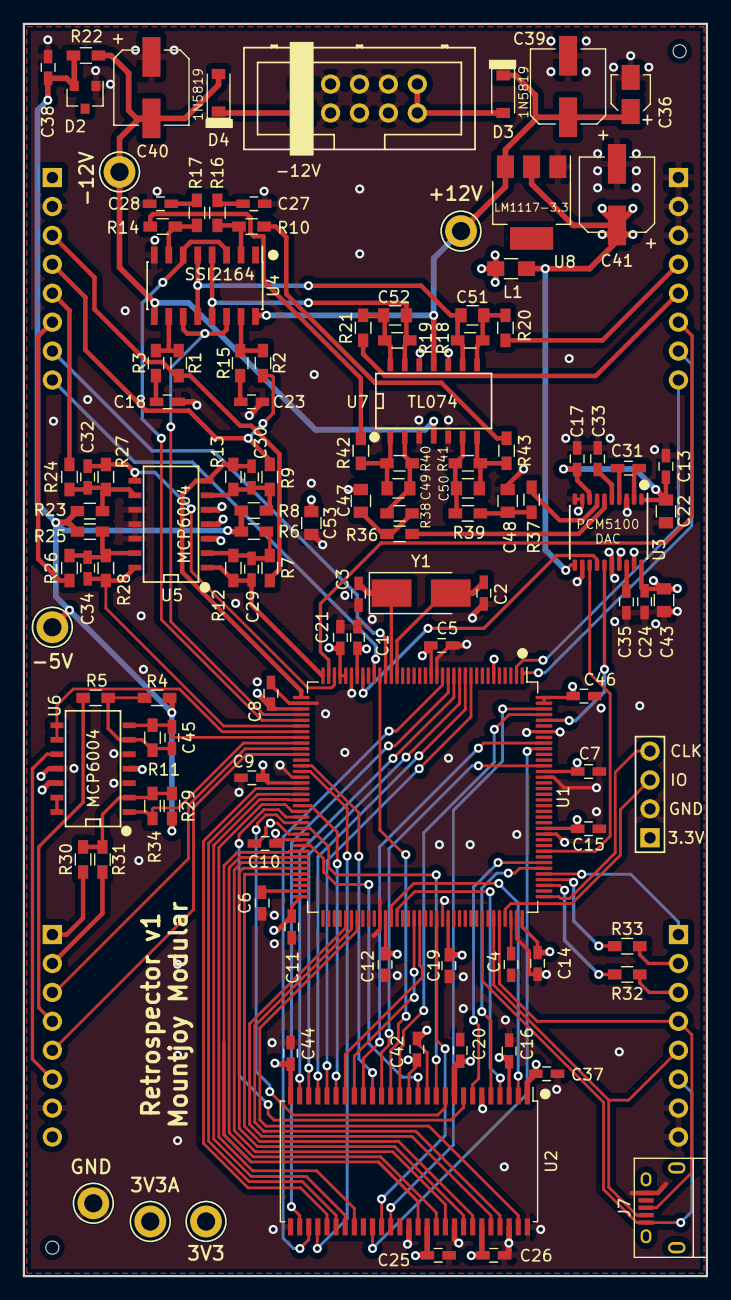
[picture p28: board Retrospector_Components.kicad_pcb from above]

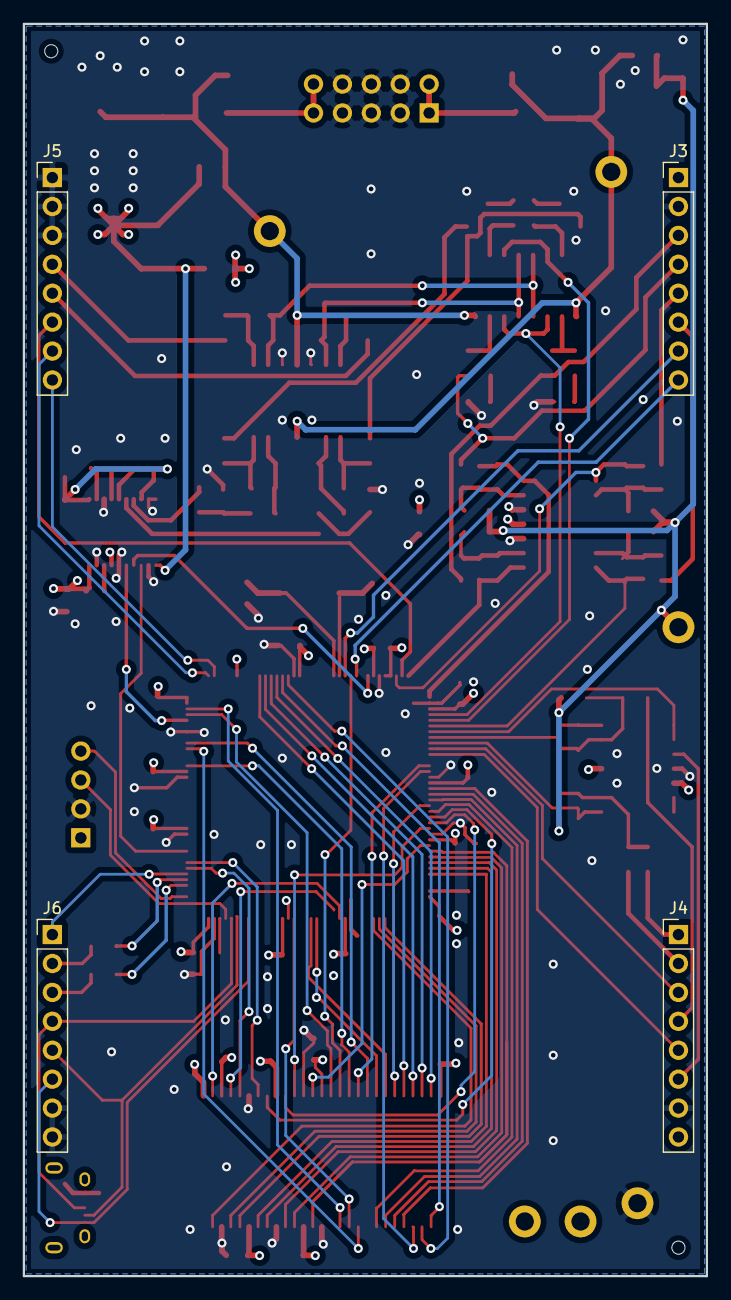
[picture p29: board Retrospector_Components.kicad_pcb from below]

Board: 4 copper layers, 60.0 x 110.0 mm, 123 parts (4 on the bottom side), 122 nets.

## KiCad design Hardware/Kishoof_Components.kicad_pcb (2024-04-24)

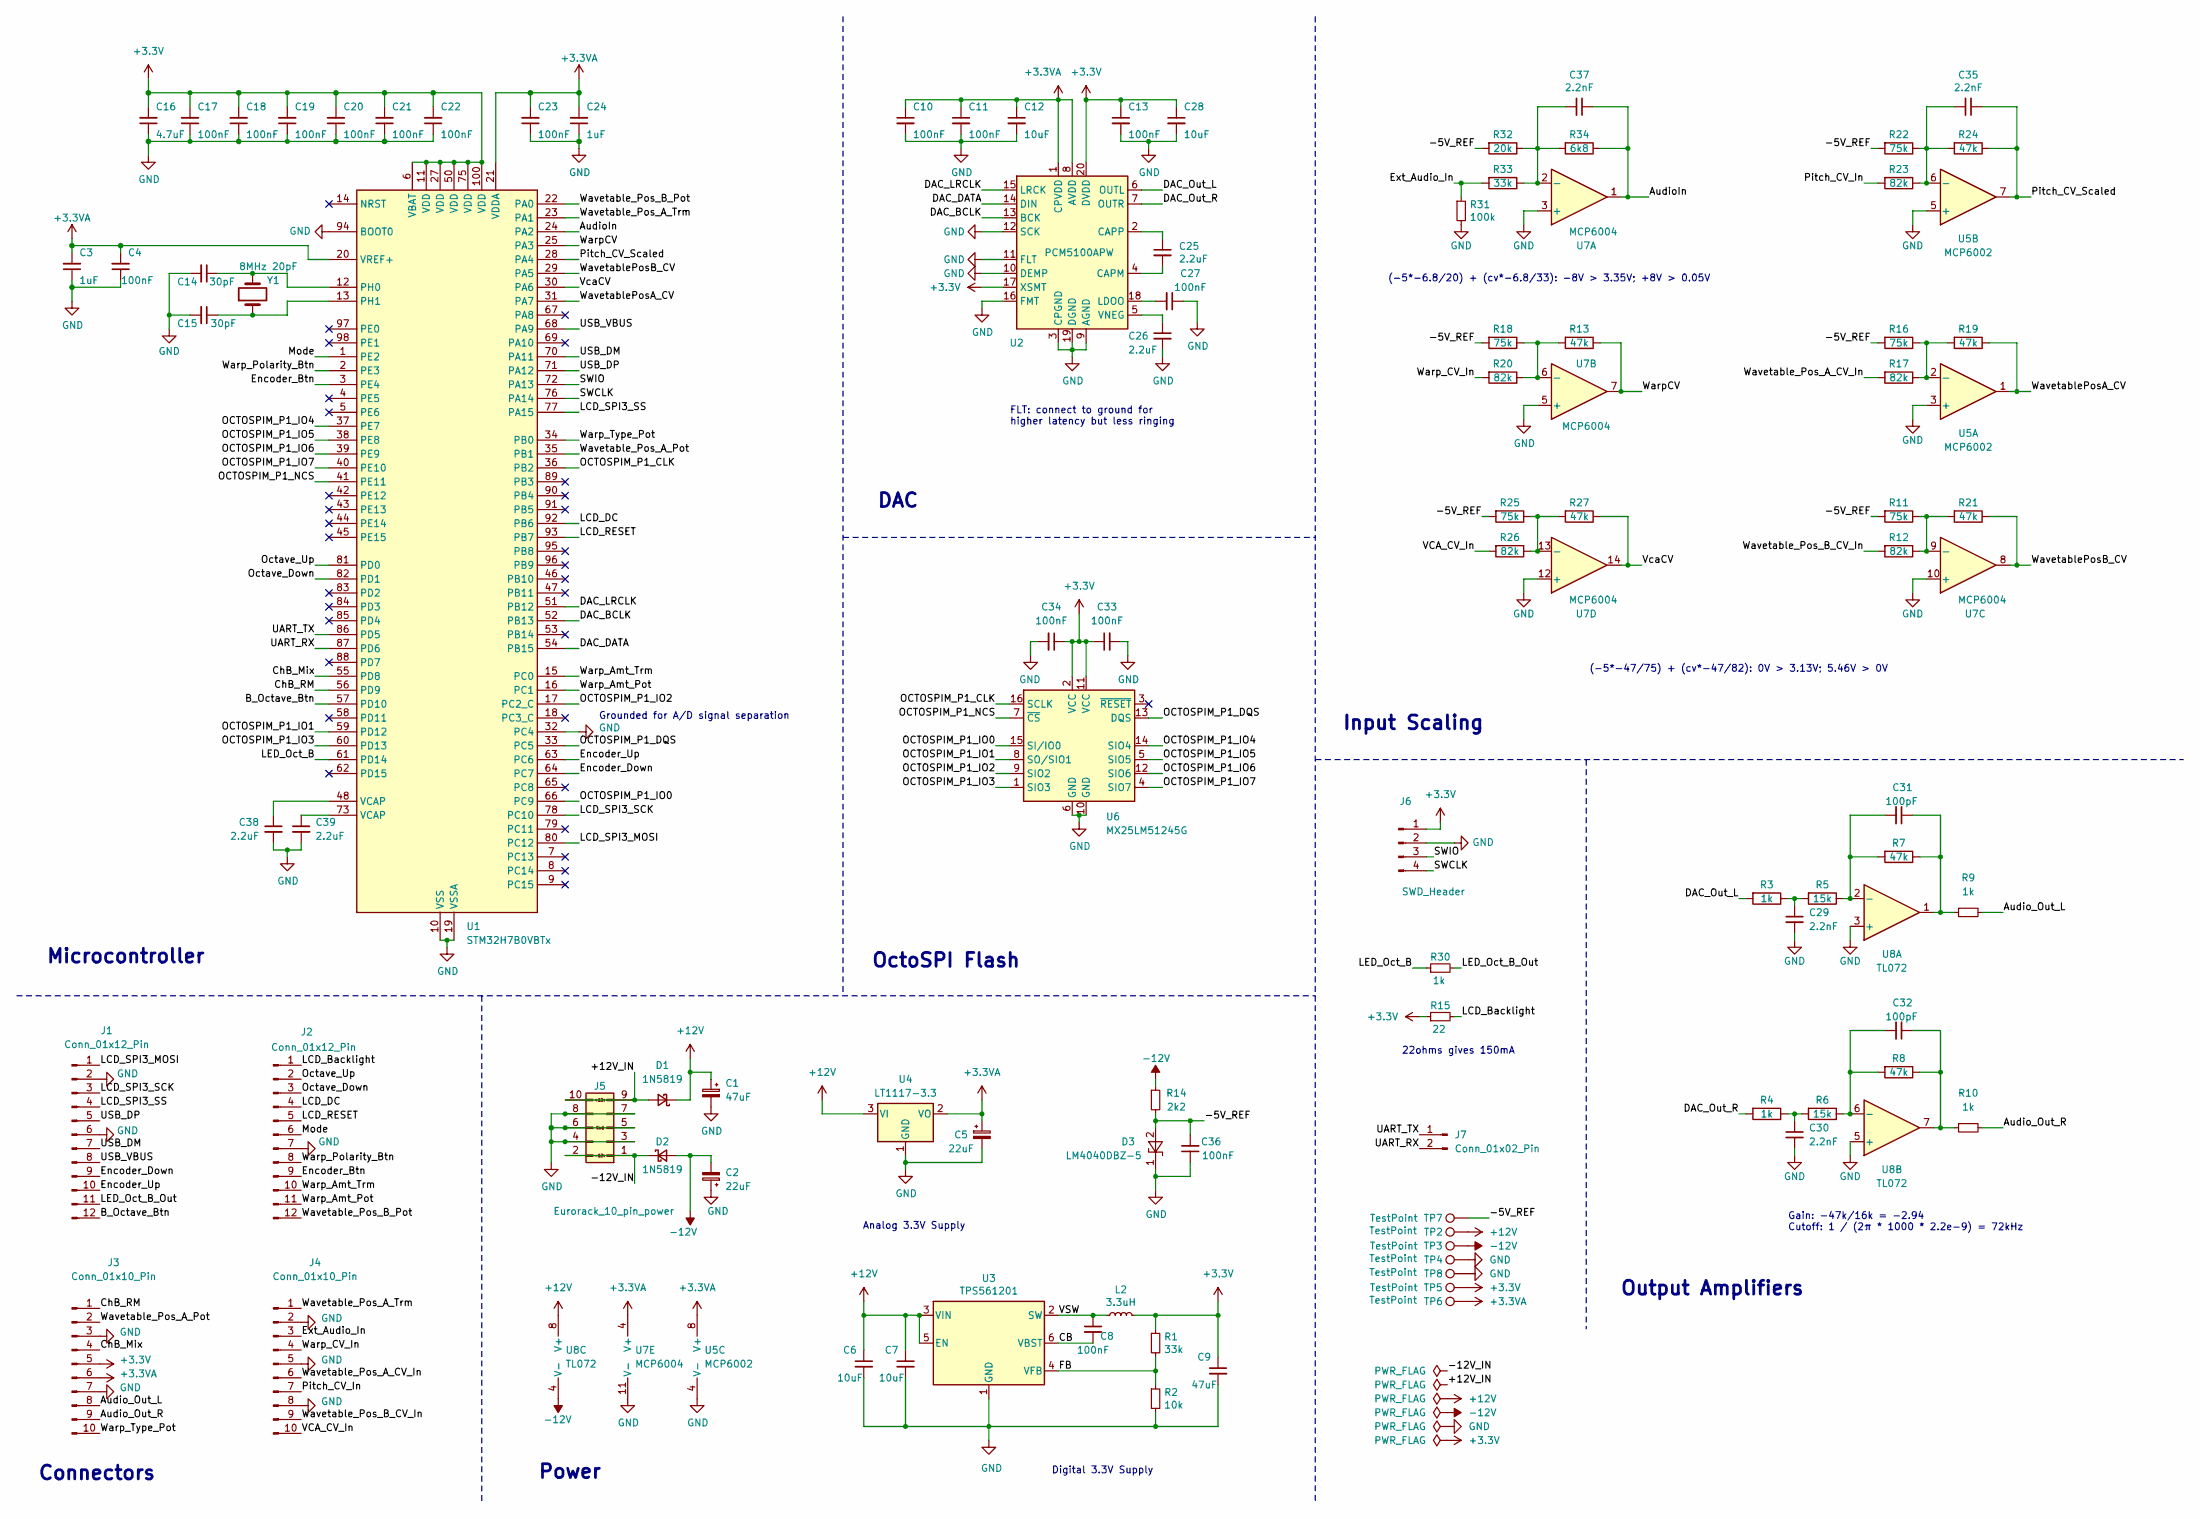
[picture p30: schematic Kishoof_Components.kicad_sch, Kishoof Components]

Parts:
C1: 47uF; CP_Elec_4x5.8
C2: 22uF; CP_Elec_4x5.8
C3, C24: 1uF; C_0603_1608Metric; Part_Number C15849
C4, C8, C10, C11, C13, C17, C18, C19, C20, C21, C22, C27, C33, C34, C36: 100nF; C_0603_1608Metric; Part_Number C14663
C5: 22uF; CP_Elec_4x5.8; Part_Number C134793
C6, C7: 10uF; C_0805_2012Metric; Part_Number C57112
C9: 47uF; C_1206_3216Metric; Part_Number C57112
C12, C28: 10uF; C_0603_1608Metric; Part_Number C15850
C14, C15: 30pF; C_0603_1608Metric; Part_Number C22397
C16: 4.7uF; C_0603_1608Metric; Part_Number C19666
C23: 100nF; C_0603_1608Metric; Part_Number C57112
C25, C26, C38, C39: 2.2uF; C_0603_1608Metric; Part_Number C23630
C29, C30, C35, C37: 2.2nF; C_0603_1608Metric; Part_Number C1604
C31, C32: 100pF; C_0603_1608Metric; Part_Number C14858
D1, D2: 1N5819; D_SOD-123; Part_Number C8598
D3: LM4040DBZ-5; SOT-23; Part_Number C156291
J1, J2: Conn_01x12_Pin; PinHeader_1x12_P2.54mm_Vertical
J3, J4: Conn_01x10_Pin; PinHeader_1x10_P2.54mm_Vertical
J5: Eurorack_10_pin_power; Eurorack_10_pin_header
J6: SWD_Header; SWD_header
J7: Conn_01x02_Pin; PinHeader_1x02_P2.54mm_Vertical
L2: 3.3uH; L_0806
R1, R33: 33k; R_0603_1608Metric; Part_Number C25819
R2: 10k; R_0603_1608Metric; Part_Number C25804
R3, R4, R9, R10, R30: 1k; R_0603_1608Metric; Part_Number C4190
R5, R6: 15k; R_0603_1608Metric; Part_Number C25804
R7, R8, R13, R19, R21, R24, R27: 47k; R_0603_1608Metric; Part_Number C25819
R11, R16, R18, R22, R25: 75k; R_0603_1608Metric; Part_Number C23242
R12, R17, R20, R23, R26: 82k; R_0603_1608Metric; Part_Number C23265
R14: 2k2; R_0603_1608Metric; Part_Number C4190
R15: 22; R_0603_1608Metric; Part_Number C23345
R31: 100k; R_0603_1608Metric; Part_Number C25803
R32: 20k; R_0603_1608Metric; Part_Number C4184
R34: 6k8; R_0603_1608Metric; Part_Number C23212
TP2, TP3, TP4, TP5, TP6, TP7, TP8: TestPoint; 1.3mm_Test_Point
U1: STM32H7B0VBTx; LQFP-100_14x14mm_P0.5mm
U2: PCM5100APW; TSSOP-20_4.4x6.5mm_P0.65mm
U3: TPS561201; TSOT-23-6_HandSoldering
U4: LT1117-3.3; SOT-223-3_TabPin2
U5: MCP6002; SOIC-8_3.9x4.9mm_P1.27mm
U6: MX25LM51245G; SOIC-16W_7.5x10.3mm_P1.27mm
U7: MCP6004; SO-14_3.9x8.65mm_P1.27mm
U8: TL072; SOIC-8_3.9x4.9mm_P1.27mm; Part_Number C6961
Y1: 8MHz 20pF; Crystal_SMD_Abracon_ABM3-2Pin_5.0x3.2mm; Part_Number C115962

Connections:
+3.3V: C9.1, C13.1, C16.2, C17.2, C18.2, C19.2, C20.2, C21.2, C22.2, C28.1, C33.1, C34.1, J3.5, J6.1, L2.2, R1.1, R15.1, TP5.1, U1.6 (VBAT), U1.11 (VDD), U1.27 (VDD), U1.50 (VDD), U1.75 (VDD), U1.100 (VDD), U2.17 (XSMT), U2.20 (DVDD), U6.2 (VCC), U6.11 (VCC)
+3.3VA: C3.2, C4.2, C5.1, C10.1, C11.1, C12.1, C23.2, C24.2, J3.6, TP6.1, U1.20 (VREF+), U1.21 (VDDA), U2.1 (CPVDD), U2.8 (AVDD), U4.2 (VO), U5.8 (V+), U7.4 (V+)
+12V: C1.1, C6.1, C7.1, D1.1 (K), TP2.1, U3.3 (VIN), U3.5 (EN), U4.3 (VI), U8.8 (V+)
-12V: C2.2, D2.2 (A), R14.1, TP3.1, U8.4 (V-)
/+12V_IN: D1.2 (A), J5.9, J5.10
/-5V_REF: C36.2, D3.2 (A), R11.2, R14.2, R16.2, R18.2, R22.2, R25.2, R32.2, TP7.1
/-12V_IN: D2.1 (K), J5.1, J5.2
/AudioIn: C37.1, R34.1, U1.24 (PA2), U7.1
/Audio_Out_L: J3.8, R9.2
/Audio_Out_R: J3.9, R10.2
/B_Octave_Btn: J1.12, U1.57 (PD10)
/CB: C8.2, U3.6 (VBST)
/ChB_Mix: J3.4, U1.55 (PD8)
/ChB_RM: J3.1, U1.56 (PD9)
/DAC_BCLK: U1.52 (PB13), U2.13 (BCK)
/DAC_DATA: U1.54 (PB15), U2.14 (DIN)
/DAC_LRCLK: U1.51 (PB12), U2.15 (LRCK)
/DAC_Out_L: R3.2, U2.6 (OUTL)
/DAC_Out_R: R4.2, U2.7 (OUTR)
/Encoder_Btn: J2.9, U1.3 (PE4)
/Encoder_Down: J1.9, U1.64 (PC7)
/Encoder_Up: J1.10, U1.63 (PC6)
/Ext_Audio_In: J4.3, R31.1, R33.2
/FB: R1.2, R2.1, U3.4 (VFB)
/LCD_Backlight: J2.1, R15.2
/LCD_DC: J2.4, U1.92 (PB6)
/LCD_RESET: J2.5, U1.93 (PB7)
/LCD_SPI3_MOSI: J1.1, U1.80 (PC12)
/LCD_SPI3_SCK: J1.3, U1.78 (PC10)
/LCD_SPI3_SS: J1.4, U1.77 (PA15)
/LED_Oct_B: R30.1, U1.61 (PD14)
/LED_Oct_B_Out: J1.11, R30.2
/Mode: J2.6, U1.1 (PE2)
/OCTOSPIM_P1_CLK: U1.36 (PB2), U6.16 (SCLK)
/OCTOSPIM_P1_DQS: U1.33 (PC5), U6.13 (DQS)
/OCTOSPIM_P1_IO0: U1.66 (PC9), U6.15 (SI/IO0)
/OCTOSPIM_P1_IO1: U1.59 (PD12), U6.8 (SO/SIO1)
/OCTOSPIM_P1_IO2: U1.17 (PC2_C), U6.9 (SIO2)
/OCTOSPIM_P1_IO3: U1.60 (PD13), U6.1 (SIO3)
/OCTOSPIM_P1_IO4: U1.37 (PE7), U6.14 (SIO4)
/OCTOSPIM_P1_IO5: U1.38 (PE8), U6.5 (SIO5)
/OCTOSPIM_P1_IO6: U1.39 (PE9), U6.12 (SIO6)
/OCTOSPIM_P1_IO7: U1.40 (PE10), U6.4 (SIO7)
/OCTOSPIM_P1_NCS: U1.41 (PE11), U6.7 (~CS)
/Octave_Down: J2.3, U1.82 (PD1)
/Octave_Up: J2.2, U1.81 (PD0)
/Pitch_CV_In: J4.7, R23.2
/Pitch_CV_Scaled: C35.1, R24.1, U1.28 (PA4), U5.7
/SWCLK: J6.4, U1.76 (PA14)
/SWIO: J6.3, U1.72 (PA13)
/UART_RX: J7.2, U1.87 (PD6)
/UART_TX: J7.1, U1.86 (PD5)
/USB_DM: J1.7, U1.70 (PA11)
/USB_DP: J1.5, U1.71 (PA12)
/USB_VBUS: J1.8, U1.68 (PA9)
/VCA_CV_In: J4.10, R26.2
/VSW: C8.1, L2.1, U3.2 (SW)
/VcaCV: R27.1, U1.30 (PA6), U7.14
/WarpCV: R13.1, U1.25 (PA3), U7.7
/Warp_Amt_Pot: J2.11, U1.16 (PC1)
/Warp_Amt_Trm: J2.10, U1.15 (PC0)
/Warp_CV_In: J4.4, R20.2
/Warp_Polarity_Btn: J2.8, U1.2 (PE3)
/Warp_Type_Pot: J3.10, U1.34 (PB0)
/WavetablePosA_CV: R19.1, U1.31 (PA7), U5.1
/WavetablePosB_CV: R21.1, U1.29 (PA5), U7.8
/Wavetable_Pos_A_CV_In: J4.6, R17.2
/Wavetable_Pos_A_Pot: J3.2, U1.35 (PB1)
/Wavetable_Pos_A_Trm: J4.1, U1.23 (PA1)
/Wavetable_Pos_B_CV_In: J4.9, R12.2
/Wavetable_Pos_B_Pot: J2.12, U1.22 (PA0)
GND: C1.2, C2.1, C3.1, C4.1, C5.2, C6.2, C7.2, C9.2, C10.2, C11.2, C12.2, C13.2, C14.2, C15.2, C16.1, C17.1, C18.1, C19.1, C20.1, C21.1, C22.1, C23.1, C24.1, C26.2, C27.1, C28.2, C29.2, C30.2, C33.2, C34.2, C36.1, C38.2, C39.2, D3.1 (K), J1.2, J1.6, J2.7, J3.3, J3.7, J4.2, J4.5, J4.8, J5.3, J5.4, J5.5, J5.6, J5.7, J5.8, J6.2, R2.2, R31.2, TP4.1, TP8.1, U1.10 (VSS), U1.19 (VSSA), U1.26 (VSS), U1.32 (PC4), U1.49 (VSS), U1.74 (VSS), U1.94 (BOOT0), U1.99 (VSS), U2.3 (CPGND), U2.9 (AGND), U2.10 (DEMP), U2.11 (FLT), U2.12 (SCK), U2.16 (FMT), U2.19 (DGND), U3.1 (GND), U4.1 (GND), U5.3 (+), U5.4 (V-), U5.5 (+), U6.6 (GND), U6.10 (GND), U7.3 (+), U7.5 (+), U7.10 (+), U7.11 (V-), U7.12 (+), U8.3 (+), U8.5 (+)
unnamed: C29.1, R3.1, R5.2
unnamed: C30.1, R4.1, R6.2
unnamed: C31.1, R7.1, R9.1, U8.1
unnamed: C32.1, R8.1, R10.1, U8.7
unnamed: C38.1, U1.48 (VCAP)
unnamed: C39.1, U1.73 (VCAP)
unnamed: C14.1, U1.12 (PH0), Y1.2
unnamed: C15.1, U1.13 (PH1), Y1.1
unnamed: C25.2, U2.4 (CAPM)
unnamed: C25.1, U2.2 (CAPP)
unnamed: C27.2, U2.18 (LDOO)
unnamed: C26.1, U2.5 (VNEG)
unnamed: R16.1, R17.1, R19.2, U5.2 (-)
unnamed: C35.2, R22.1, R23.1, R24.2, U5.6 (-)
unnamed: C37.2, R32.1, R33.1, R34.2, U7.2 (-)
unnamed: R13.2, R18.1, R20.1, U7.6 (-)
unnamed: R11.1, R12.1, R21.2, U7.9 (-)
unnamed: R25.1, R26.1, R27.2, U7.13 (-)
unnamed: C31.2, R5.1, R7.2, U8.2 (-)
unnamed: C32.2, R6.1, R8.2, U8.6 (-)

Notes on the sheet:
DAC
Gain: -47k/16k = -2.94 Cutoff: 1 / (2π * 1000 * 2.2e-9) = 72kHz
Connectors
FLT: connect to ground for higher latency but less ringing
Digital 3.3V Supply
(-5*-47/75) + (cv*-47/82): 0V > 3.13V; 5.46V > 0V
OctoSPI Flash
Input Scaling
Output Amplifiers
Grounded for A/D signal separation
Power
Analog 3.3V Supply
Microcontroller
22ohms gives 150mA
(-5*-6.8/20) + (cv*-6.8/33): -8V > 3.35V; +8V > 0.05V

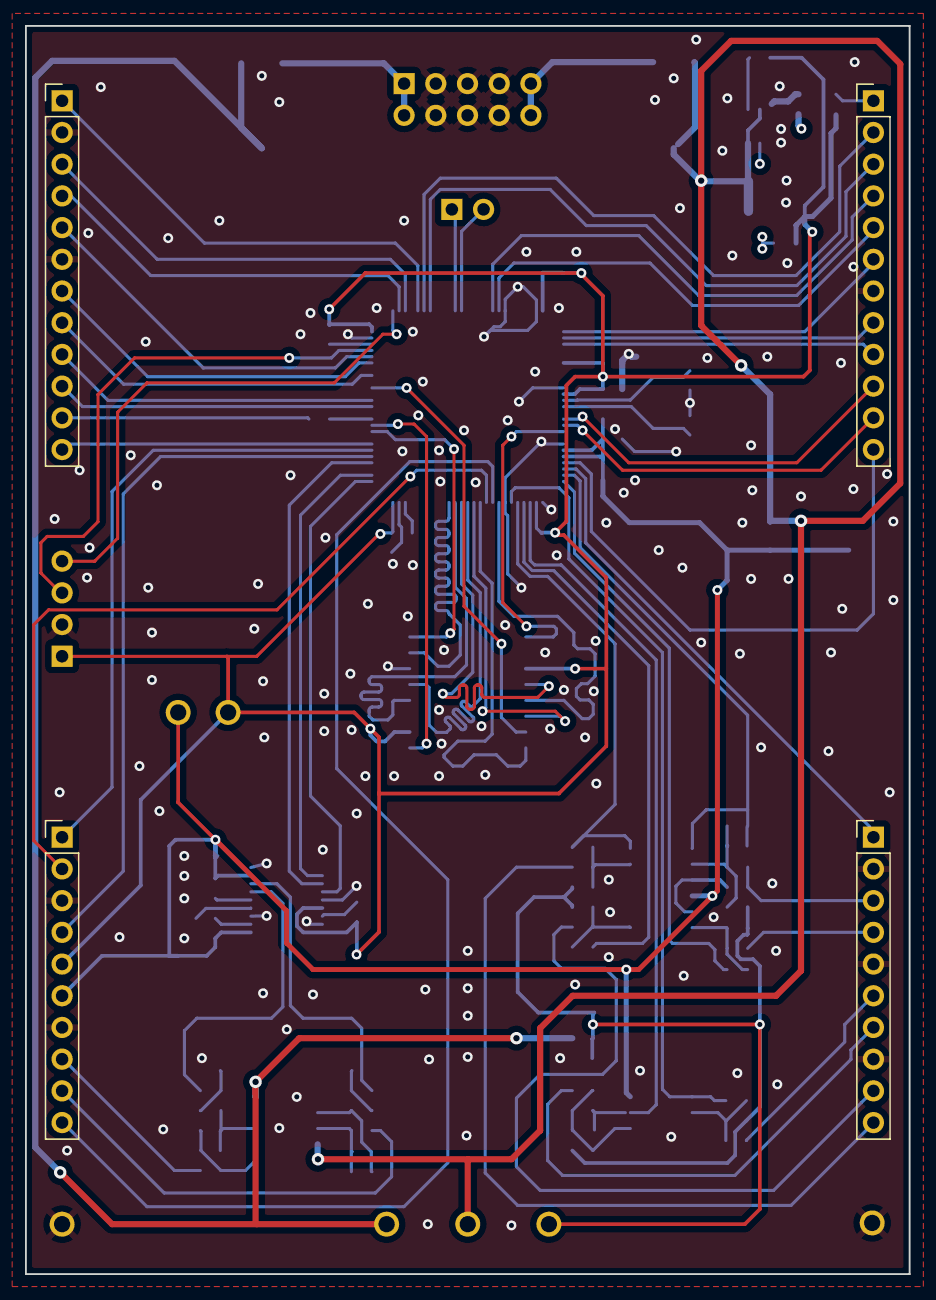
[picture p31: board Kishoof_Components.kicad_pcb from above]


Board: 4 copper layers, 70.8 x 100.0 mm, 98 parts (94 on the bottom side), 92 nets.

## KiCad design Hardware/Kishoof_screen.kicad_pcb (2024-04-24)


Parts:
J1, J2, J3, J4: Conn_01x02_Socket; PinHeader_1x02_P2.54mm_Vertical
U1: Round_LCD

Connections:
+3.3V: J4.1, U1.4 (VDD)
/LCD_BACKLIGHT: J4.2, U1.3 (LEDA)
/LCD_DC: J2.1, U1.7 (D/C)
/LCD_RESET: J2.2, U1.11 (RESET)
/LCD_SPI3_MOSI: J1.1, U1.10 (SDA)
/LCD_SPI3_SCK: J1.2, U1.9 (SCL)
/LCD_SPI3_SS: J3.1, U1.8 (~CS)
GND: J3.2, U1.1 (GND), U1.2 (LEDK), U1.5 (GND), U1.6 (GND), U1.12 (GND)



Board: 2 copper layers, 39.0 x 41.0 mm, 5 parts (5 on the bottom side), 8 nets.

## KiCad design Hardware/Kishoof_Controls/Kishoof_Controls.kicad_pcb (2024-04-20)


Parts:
D4: LED_Small; LED_D3.0mm_FlatTop
J3: WavetablePosA; THONKICONN_hole
J4: WavetablePosB; THONKICONN_hole
J5: WarpCV; THONKICONN_hole
J6: VOct; THONKICONN_hole
J7: VCA; THONKICONN_hole
J8: Audio_Out_L; THONKICONN_hole
J9: Audio_Out_R; THONKICONN_hole
J10: USB_C_Receptacle; USB_C_Receptacle_Amphenol_12401951E412A
J11: Conn_01x02_Pin; PinHeader_1x02_P2.54mm_Vertical
J12: Conn_01x01_Socket; PinHeader_1x01_P2.54mm_Vertical
JP1: Jumper; SolderJumper-2_P1.3mm_Open_RoundedPad1.0x1.5mm
R28, R29: 5k1; R_0603_1608Metric; Part_Number C23186
SW1: SW_Push; SW_PUSH_6mm_aligned
SW2: Mode_Switch; SPDT_Miniature
SW3: Octave_Switch; SP3T_Mini_Switch
SW4: ChB_Output; SP3T_Mini_Switch
SW5: Encoder
U9: STF202-22T1G
U10: LCD_Riser
WarpAmtPot1: B10k; Alpha_9mm_Potentiometer_Aligned
WarpAmtTrm1: B10k; Alpha_9mm_Potentiometer_Aligned
WarpType1: WarpTypePot; Bourns_Switch_Potentiometer
WavetableAPot1: B10k; Alpha_9mm_Potentiometer_Aligned
WavetableATrm1: B10k; Alpha_9mm_Potentiometer_Aligned
WavetableBPot1: B10k; Alpha_9mm_Potentiometer_Aligned

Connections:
+3.3V: SW2.1 (A), SW3.2 (3), SW4.2 (3), U10.7 (VDD)
+3.3VA: WarpAmtPot1.1, WarpAmtTrm1.1, WarpType1.1, WavetableAPot1.1, WavetableATrm1.1, WavetableBPot1.1
/USB_DM: U9.2 (D1_OUT)
/USB_DP: U9.3 (D2_OUT)
Audio_Out_L: J8.3
Audio_Out_R: J9.3
B_Octave_Btn: SW1.1
ChB_Mix: SW4.1
ChB_RM: SW4.3 (4)
Encoder_Btn: SW5.S1
Encoder_Down: SW5.B
Encoder_Up: SW5.A
Ext_Audio_In: J12.1
GND: D4.1 (K), J3.1, J3.2, J4.1, J4.2, J5.1, J5.2, J6.1, J6.2, J7.1, J7.2, J8.1, J9.1, J10.A1 (GND), J10.A12 (GND), J10.B1 (GND), J10.B12 (GND), J10.S1 (SHIELD), R28.2, R29.2, SW1.2, SW2.3 (C), SW5.C, SW5.S2, U9.6 (GND), U10.6 (GND), WarpAmtPot1.3, WarpAmtTrm1.3, WarpType1.3, WarpType1.4 (1), WavetableAPot1.3, WavetableATrm1.3, WavetableBPot1.3
LCD_Backlight: U10.8 (BACKLIGHT)
LCD_DC: U10.3 (DC)
LCD_RESET: U10.4 (RESET)
LCD_SPI3_MOSI: U10.1 (MOSI)
LCD_SPI3_SCK: U10.2 (CLK)
LCD_SPI3_SS: U10.5 (CS)
LED_Oct_B_Out: D4.2 (A)
Mode: SW2.2 (B)
unnamed: J10.A5 (CC1), R28.1
unnamed: J10.B5 (CC2), R29.1
unnamed: JP1.1 (A), U9.1 (VBUS)
Octave_Down: SW3.3 (4)
Octave_Up: SW3.1
Pitch_CV_In: J6.3
UART_RX: J11.2
UART_TX: J11.1
USB_D+: J10.A6 (D+), J10.B6 (D+), U9.4 (D2_IN)
USB_D-: J10.A7 (D-), J10.B7 (D-), U9.5 (D1_IN)
USB_VBUS: J10.A4 (VBUS), J10.A9 (VBUS), J10.B4 (VBUS), J10.B9 (VBUS), JP1.2 (B)
VCA_CV_In: J7.3
Warp_Amt_Pot: WarpAmtPot1.2
Warp_Amt_Trm: WarpAmtTrm1.2
Warp_CV_In: J5.3
Warp_Polarity_Btn: WarpType1.5 (2)
Warp_Type_Pot: WarpType1.2
Wavetable_Pos_A_CV_In: J3.3
Wavetable_Pos_A_Pot: WavetableAPot1.2
Wavetable_Pos_A_Trm: WavetableATrm1.2
Wavetable_Pos_B_CV_In: J4.3
Wavetable_Pos_B_Pot: WavetableBPot1.2

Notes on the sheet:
Protection and Output



Board: 4 copper layers, 70.8 x 110.0 mm, 27 parts (6 on the bottom side), 9 nets.

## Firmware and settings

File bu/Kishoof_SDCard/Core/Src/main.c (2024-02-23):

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
/* Includes ------------------------------------------------------------------*/
#include "main.h"
#include "fatfs.h"

/* USER CODE BEGIN Includes */
#include <string.h>
/* USER CODE END Includes */


SD_HandleTypeDef hsd1;

void SystemClock_Config(void);
static void MX_GPIO_Init(void);
static void MX_SDMMC1_SD_Init(void);
/**
 * @brief  The application entry point.
 * @retval int
 */
int main(void)
{
	/* USER CODE BEGIN 1 */
	FRESULT res; 									// FatFs function common result code
	uint32_t byteswritten, bytesread;				// File write/read counts
	uint8_t wtext[] = "STM32 FATFS works great!";	// File write buffer
	uint8_t rtext[_MAX_SS];							// File read buffer
	/* USER CODE END 1 */

	/* MCU Configuration--------------------------------------------------------*/

	/* Reset of all peripherals, Initializes the Flash interface and the Systick. */
	HAL_Init();

	/* Configure the system clock */
	SystemClock_Config();

	/* Initialize all configured peripherals */
	MX_GPIO_Init();
	MX_SDMMC1_SD_Init();
	MX_FATFS_Init();
	/* USER CODE BEGIN 2 */
	if (0) {
		if (f_mount(&SDFatFS, (TCHAR const*)SDPath, 1) != FR_OK)	{
			Error_Handler();
		} else {
			res = f_mkfs((TCHAR const*)SDPath, FM_ANY, 0, rtext, sizeof(rtext));
			if (res != FR_OK) {
				Error_Handler();
			} else {
				//Open file for writing (Create)
				if (f_open(&SDFile, "STM32.TXT", FA_CREATE_ALWAYS | FA_WRITE) != FR_OK) {
					Error_Handler();
				} else {
					//Write to the text file
					res = f_write(&SDFile, wtext, strlen((char*)wtext), (void*)&byteswritten);
					if ((byteswritten == 0) || (res != FR_OK)) {
						Error_Handler();
					} else {
						f_close(&SDFile);

						// Open the text file object with read access
						if (f_open(&SDFile, "STM32.TXT", FA_READ) == FR_OK) {

							// Read data from the text file
							res = f_read(&SDFile, rtext, sizeof(rtext), (unsigned int *)&bytesread);

							if ((bytesread > 0) && (res == FR_OK)) {

								//Close the open text file
								f_close(&SDFile);
							}
						}
					}
				}

			}

		}
	}
	res = f_mount(&SDFatFS, (TCHAR const*)SDPath, 1);

	DIR dp;						// Pointer to the directory object structure
	FILINFO fno;				// File information structure
	res = f_opendir(&dp, "");	// second parm is directory name (root)
	res = f_readdir(&dp, &fno);

	const char* testFile = "STM32.TXT";
	if (f_open(&SDFile, testFile, FA_READ) == FR_OK) {

		// Read data from the text file
		res = f_read(&SDFile, rtext, sizeof(rtext), (unsigned int *)&bytesread);

		if ((bytesread > 0) && (res == FR_OK)) {

			//Close the open text file
			f_close(&SDFile);
		}
	}

	uint8_t dummy = 1;


	/* USER CODE END 2 */

	/* Infinite loop */
	/* USER CODE BEGIN WHILE */
	while (1)
	{
		/* USER CODE END WHILE */

		/* USER CODE BEGIN 3 */
	}
	/* USER CODE END 3 */
}

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


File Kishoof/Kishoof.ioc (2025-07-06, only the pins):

Mcu.UserName=STM32H7B0VBTx
PA0.Signal=ADC1_INP16
PA1.Signal=ADC1_INP17
PA11.Signal=USB_OTG_HS_DM
PA12.Signal=USB_OTG_HS_DP
PA15.Signal=SPI3_NSS
PA2.Signal=ADCx_INP14
PA3.Signal=ADC1_INP15
PA4.Signal=ADCx_INP18
PA5.Signal=ADCx_INP19
PA6.Signal=ADCx_INP3
PA7.Signal=ADCx_INP7
PA9.Signal=USB_OTG_HS_VBUS
PB0.Signal=ADCx_INP9
PB1.Signal=ADCx_INP5
PB12.Signal=I2S2_WS
PB13.Signal=I2S2_CK
PB15.Signal=I2S2_SDO
PB2.Signal=OCTOSPIM_P1_CLK
PB6.GPIO_Label=LCD_DC
PB6.Signal=GPIO_Input
PB7.GPIO_Label=LCD_RESET
PB7.Signal=GPIO_Input
PC0.Signal=ADCx_INP10
PC1.Signal=ADCx_INP11
PC10.Signal=SPI3_SCK
PC12.Signal=SPI3_MOSI
PC2_C.Signal=OCTOSPIM_P1_IO2
PC5.Signal=OCTOSPIM_P1_DQS
PC6.Signal=S_TIM3_CH1
PC7.Signal=S_TIM3_CH2
PC9.Signal=OCTOSPIM_P1_IO0
PD0.GPIO_Label=Octave_Up
PD0.Signal=GPIO_Input
PD1.GPIO_Label=Octave_Down
PD1.Signal=GPIO_Input
PD10.GPIO_Label=B_Octave_Btn
PD10.Signal=GPIO_Input
PD12.Signal=OCTOSPIM_P1_IO1
PD13.Signal=OCTOSPIM_P1_IO3
PD14.Signal=S_TIM4_CH3
PD5.Signal=USART2_TX
PD6.Signal=USART2_RX
PD8.GPIO_Label=ChB_Mix
PD8.Signal=GPIO_Input
PD9.GPIO_Label=ChB_RM
PD9.Signal=GPIO_Input
PE10.Signal=OCTOSPIM_P1_IO7
PE11.Signal=OCTOSPIM_P1_NCS
PE2.GPIO_Label=Mode
PE2.Signal=GPIO_Input
PE3.GPIO_Label=Warp_Polarity_Btn
PE3.Signal=GPIO_Input
PE4.GPIO_Label=ENCODER_BTN
PE4.Signal=GPIO_Input
PE7.Signal=OCTOSPIM_P1_IO4
PE8.Signal=OCTOSPIM_P1_IO5
PE9.Signal=OCTOSPIM_P1_IO6
PH0-OSC_IN.Signal=RCC_OSC_IN
PH1-OSC_OUT.Signal=RCC_OSC_OUT

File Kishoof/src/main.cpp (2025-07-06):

#include "initialisation.h"
#include "CDCHandler.h"
#include "USB.h"
#include "WaveTable.h"
#include "configManager.h"
#include "Calib.h"
#include "Filter.h"
#include "lcd.h"
#include "ExtFlash.h"
#include "UI.h"
#include "uartHandler.h"

volatile uint32_t SysTickVal;
extern uint32_t SystemCoreClock;
bool SafeMode = false;				// Disables file system mounting, USB MSC drive is disabled, don't load config

volatile ADCValues __attribute__((section (".dma_buffer"))) adc;	// Store adc buffer in non-cached memory area

Config config{&wavetable.configSaver, &calib.configSaver, &ui.configSaver};		// Construct config handler with list of configSavers

extern "C" {
#include "interrupts.h"
}

bool USBDebug = false;

int main(void) {

	InitClocks();					// Configure the clock and PLL
	InitHardware();


	if (GpioPin::IsLow(GPIOE, 4)) {	// If encoder button is pressed enter 'safe-mode'
		SafeMode = true;
	}

	lcd.Init();
	extFlash.Init();
	filter.Init();					// Initialise look up table of filter coefficients, windows etc
	if (!SafeMode) {
		config.RestoreConfig();
	}
	wavetable.Init();
	usb.Init(false);
	InitI2S();						// Initialise I2S which will start main sample interrupts

	while (1) {
		usb.cdc.ProcessCommand();	// Check for incoming USB serial commands
		ui.Update();
		fatTools.CheckCache();		// Check if any outstanding cache changes need to be written to Flash
		config.SaveConfig();		// Save any scheduled changes
		CheckVCA();					// Bodge to check if VCA is normalled to 3.3v
		calib.Calibrate();
#if (USB_DEBUG)
		uart.ProcessCommand();
#endif

	}
}

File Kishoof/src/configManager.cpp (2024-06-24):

#include "configManager.h"
#include <cstring>
#include <cstdio>


bool Config::SaveConfig(const bool forceSave)
{
	bool result = true;
	if (forceSave || (scheduleSave && SysTickVal > saveBooked + 60000)) {			// 60 seconds between saves
		GpioPin::SetHigh(GPIOD, 5);
		scheduleSave = false;

		if (currentSettingsOffset == -1) {					// Default = -1 if not first set in RestoreConfig
			currentSettingsOffset = 0;
		} else {
			currentSettingsOffset += settingsSize;
			if ((uint32_t)currentSettingsOffset > flashSectorSize - settingsSize) {
				// Check if another sector is available for use
				for (auto& sector : sectors) {
					if (!sector.dirty && sector.sector != currentSector) {
						if (++currentIndex > configSectorCount) { 	// set new index, wrapping at count of allowed config sectors
							currentIndex = 0;
						}
						currentSector = sector.sector;
						SetCurrentConfigAddr();
						currentSettingsOffset = 0;
						sector.index = currentIndex;
						sector.dirty = true;
						break;
					}
				}
				if (currentSettingsOffset != 0) {				// No free configurations slots found - abort save
					printf("Error saving config - no space\r\n");
					return false;
				}
			}
		}
		uint32_t* flashPos = flashConfigAddr + currentSettingsOffset / 4;


		uint8_t configBuffer[settingsSize];					// Will hold all the data to be written by config savers
		memcpy(configBuffer, ConfigHeader, 4);
		configBuffer[4] = currentIndex;						// Store the index of the config to identify the active sector
		uint32_t configPos = headerSize;
		for (auto& saver : configSavers) {					// Add individual config settings to buffer after header
			memcpy(&configBuffer[configPos], saver->settingsAddress, saver->settingsSize);
			configPos += saver->settingsSize;
		}

		FlashUnlock();										// Unlock Flash memory for writing
		FLASH->CCR1 = flashAllErrors;						// Clear error flags in Status Register
		result = FlashProgram(flashPos, reinterpret_cast<uint32_t*>(&configBuffer), settingsSize);
		FlashLock();										// Lock Flash

		if (result) {
			printf("Config Saved (%lu bytes at %#010lx)\r\n", settingsSize, (uint32_t)flashPos);
		} else {
			printf("Error saving config\r\n");
		}
		GpioPin::SetLow(GPIOD, 5);
	}
	return result;
}


void Config::RestoreConfig()
{
	// Initialise sector array - used to manage which sector contains current config, and which sectors are available for writing when current sector full
	for (uint32_t i = 0; i < configSectorCount; ++i) {
		sectors[i].sector = flashConfigSector + i;
		uint32_t* const addr = flashConfigAddr + i * (flashSectorSize / 4);

		// Check if sector is dirty
		for (uint32_t w = 0; w < (flashSectorSize / 4); ++w) {
			if (addr[w] != 0xFFFFFFFF) {
				sectors[i].dirty = true;
				break;
			}
		}

		// Check if there is a config block at the start of the sector and read the index number if so
		sectors[i].index = (addr[0] == *(uint32_t*)ConfigHeader) ? (uint8_t)addr[1] : 255;
	}

	// Work out which is the active config sector: will be the highest index from the bottom before the sequence jumps
	std::sort(sectors.begin(), sectors.end(), [](const CfgSector& l, const CfgSector& r) { return l.index < r.index; });
	uint32_t index = sectors[0].index;
	if (index == 255) {
		currentSector = flashConfigSector;
		currentIndex = 0;					// Each sector is assigned an index to determine which contains the latest config
	} else {
		currentSector = sectors[0].sector;
		for (uint32_t i = 1; i < configSectorCount; ++i) {
			if (sectors[i].index == index + 1) {
				++index;
				currentSector = sectors[i].sector;
			} else {
				break;
			}
		}
		currentIndex = index;
	}
	SetCurrentConfigAddr();				// Set the base address of the sector holding the current config

	// Erase any dirty sectors that are not the current one, or do not contain config data
	for (auto& sector : sectors) {
		if (sector.dirty && (sector.sector != currentSector || sector.index == 255)) {
			FlashEraseSector(sector.sector);
			sector.index = 255;
			sector.dirty = false;
		}
	}
	std::sort(sectors.begin(), sectors.end(), [](const CfgSector& l, const CfgSector& r) { return l.sector < r.sector; });

	// Locate latest (active) config block
	uint32_t pos = 0;
	while (pos <= flashSectorSize - settingsSize) {
		if (*(flashConfigAddr + pos / 4) == *(uint32_t*)ConfigHeader) {
			currentSettingsOffset = pos;
			pos += settingsSize;
		} else {
			break;			// Either reached the end of the sector or found the latest valid config block
		}
	}

	if (currentSettingsOffset >= 0) {
		const uint8_t* flashConfig = reinterpret_cast<uint8_t*>(flashConfigAddr) + currentSettingsOffset;
		uint32_t configPos = headerSize;		// Position in buffer to retrieve settings from

		// Restore settings
		for (auto saver : configSavers) {
			memcpy(saver->settingsAddress, &flashConfig[configPos], saver->settingsSize);
			if (saver->validateSettings != nullptr) {
				saver->validateSettings();
			}
			configPos += saver->settingsSize;
		}
	}
}
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

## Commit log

2024-02-06 Test code allows custom wave tables to be tested with potentiometer controlled pitch
2024-02-08 Various updates to test wavetable and filtering code
2024-02-10 Experimenting with combining sample interpolation and filtering
2024-02-10 Fixed issue with divide by zero
    [WaveTable.cpp]
2024-02-11 Now supports pitch CV
2024-02-12 Added wavetable interpolation; anti-aliasing filters dynamically calculated
2024-02-14 Performance testing; code clean up
    [Retrospector_Components.kicad_sch]
2024-02-15 Renamed project; added Flash storage test
    [mkfs.xls, mkfs.xlsx]
2024-02-15 Wavetable playback working correctly from external dual QSPI flash
    [WaveTable.cpp, WaveTable.h, initialisation.cpp]
2024-02-17 Added botch to stop I2S interrupt firing twice
2024-02-17 Started transferring SD HAL library
    [mkfs.xls, mkfs.xlsx]
2024-02-19 Started updating interrupt handler
2024-02-20 Fixing converted SD commands
    [FatTools.h, initialisation.cpp, main.cpp]
2024-02-21 Basic FAT file system mounting and can read file; DMA not working
    [main.c]
2024-02-22 Fixed SD DMA (DMA buffers cannot live in DTCMRAM)
    [initialisation.cpp, main.cpp]
2024-02-23 writing via DMA working (cache disabled)
2024-02-26 Started adding directory detail printout
2024-02-27 Directory details shows cluster chain
2024-02-29 SD Card DMA read can now work in blocking mode
2024-03-10 Started adding LCD support
    [Retrospector_Components.kicad_pcb, Retrospector_Controls.kicad_sch]
2024-03-16 Basic setup and DMA transfer working for circular LCD display
2024-03-18 Started adding wavetable draw
    [Square_wrong.csv]
2024-03-18 Basic wavetable display working
    [Square_right.csv]
2024-03-18 Clean up wavetable draw; doubled speed of SPI
2024-03-19 Performance testing updates
    [Retrospector_Components.kicad_sch]
2024-03-19 Improved performance of screen redrawing by using DMA to blank frame buffer
2024-03-19 Reconfigured DMA memory locations to reenable data cache
2024-03-20 Increased drive strength of SPI pins
2024-03-22 Started creating component schematic
    [Kishoof_Components.kicad_pcb, Kishoof_Components.kicad_sch, Retrospector_Components.kicad_pcb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]
2024-03-22 Testing clocking at 28-MHz; SPI clock changed to /8
2024-03-23 Additional schematic layout
    [Kishoof_Components.kicad_pcb, Kishoof_Components.kicad_sch]
2024-03-25 Implemented basic stepped mode for separate wavetables on A and B
    Inverted waveform on display
    Updates to hardware design
    [Kishoof_Components.kicad_pcb, Kishoof_Components.kicad_sch, Kishoof_Panel.kicad_pcb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]
2024-03-26 Implemented basic 10 harmonic additive wave for channel B in smooth mode
    [Kishoof_Components.kicad_sch]
2024-03-27 Added botch to workaround I2S interrupt firing too early
    [Kishoof.ioc, WaveTable.cpp, WaveTable.h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]
2024-03-27 More experiments with I2S interrupt timing
2024-03-27 Started adding warp functionality
    [WaveTable.cpp, WaveTable.h]
2024-03-28 Fixed issues with divide by zero error
    [WaveTable.cpp, WaveTable.h]
2024-03-29 Work on bend and squeeze warp algorithms
    [WaveTable.cpp, WaveTable.h, initialisation.h]
2024-03-31 Added mirror and reverse warp functions
    [WaveTable.cpp, WaveTable.h]
2024-04-01 Warp type available on pot;
    started adding Warp type to LCD display
    [WaveTable.cpp, WaveTable.h, lcd.cpp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]
2024-04-01 Refactored wavetable sample interpolation into new function
2024-04-03 Rearranged Panel
    [Kishoof_Components.kicad_sch, Kishoof_Panel.kicad_pcb]
2024-04-03 Updating component and panel PCBs
    [Kishoof_Components.kicad_pcb, Kishoof_Components.kicad_sch, Kishoof_Panel.kicad_pcb]
2024-04-04 Schematic updates
    [Kishoof_Components.kicad_pcb, Kishoof_Components.kicad_sch, Kishoof_Panel_alt1.kicad_pcb]
2024-04-06 First draft signal routing on component pcb
    [Kishoof_Components.kicad_pcb, Kishoof_Components.kicad_sch, Kishoof_Panel.kicad_pcb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]
2024-04-06 Started routing power
    [Kishoof_Components.kicad_pcb, Kishoof_Components.kicad_sch]
2024-04-07 Added LCD Riser board; power routing
    [Kishoof_Components.kicad_pcb, Kishoof_Components.kicad_sch, Kishoof_screen.kicad_pcb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]
2024-04-08 Added STM32H7B0 project for testing
    [Kishoof_Components.kicad_pcb, Kishoof_Components.kicad_sch, Kishoof_screen.kicad_pcb]
2024-04-08 Updating JLC assembly part number
    [Kishoof_Components.kicad_pcb, Kishoof_Components.kicad_sch]
2024-04-09 Schematic Clean up
    [Kishoof_Components.kicad_pcb, Kishoof_Components.kicad_sch, Kishoof_Controls.kicad_sch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]
2024-04-20 Separated PCB controls and components
    [Kishoof_Components-B_Cu.gbr, Kishoof_Components-B_Mask.gbr, Kishoof_Components-B_Paste.gbr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]
2024-04-20 First pass of component board routing complete
    [Kishoof_Components.kicad_pcb, Kishoof_Components.kicad_sch]
2024-04-21 Cleaned up inter-board connectors
    [Kishoof_Components.kicad_pcb, Kishoof_Components.kicad_sch]
2024-04-22 Control board routed; updated lcd riser
    [Kishoof_Components.kicad_pcb, Kishoof_Components.kicad_sch, Kishoof_Controls.kicad_pcb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]
2024-04-24 PCBs v1.0 ordered
    [Kishoof_Components-B_Cu.gbr, Kishoof_Components-B_Mask.gbr, Kishoof_Components-B_Paste.gbr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]
2024-04-29 Preparing for bring-up on STM32H7B0
2024-04-30 Started adding Flash code
    [mkfs.xls, mkfs.xlsx]
2024-05-04 Fixes to clock and adc initialisation
    [initialisation.cpp, lcd.cpp, main.cpp]
2024-05-05 LCD SPI working
2024-05-05 Started testing USB
    Working only if delay inserted into interrupt handler at beginning
2024-05-06 Tweaks to get USB CDC working
    [Kishoof_Controls.kicad_sch]
2024-05-06 Rotary Encoder working; corrected display orientation
    [USB.cpp, WaveTable.cpp, initialisation.cpp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]
2024-05-06 Tweaks to try and resolve issues with display
    [initialisation.cpp, lcd.h]
2024-05-07 Updated linker to support dma buffer to fix lcd issues
    [USB.h, WaveTable.cpp, initialisation.cpp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]
2024-05-09 Timing tweaks on flash reset. Flash tested OK at 50MHz
    [ExtFlash.cpp]
2024-05-10 USB MSC implemented; Flash storage visible in Windows
    File storage/caching not working correctly yet
    [ExtFlash.cpp, USB.h, WaveTable.cpp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]
2024-05-11 Fixes to FatTools; added fat info function
    [FatTools.h]
2024-05-14 Handling for USB access blocking wavetable sample reads
2024-05-16 Reverted changes breaking USB file reading
    [FatTools.h, WaveTable.cpp, WaveTable.h]
2024-05-17 USB flash reads don't use MDMA to resolve USB reads hanging
    [Kishoof_Controls.kicad_sch]
2024-05-18 Changed I2S threshold from 4 data to 2 data
    Seems to have fixed FIFO underruns
    [WaveTable.cpp, WaveTable.h, initialisation.cpp]
2024-05-18 UI button handler; started USB bootloader
2024-05-19 Serial console can switch into DFU mode
2024-05-19 Implemented Channel B octave down button
2024-05-21 Implemented filter coefficient look up table
2024-05-22 Adjust anti-aliasing filter to match warp settings
    [WaveTable.cpp, WaveTable.h, main.cpp]
2024-05-24 Encoder button switches displayed channel
2024-05-27 Added calibration routine; Improved serial console info
2024-05-27 Add smoothing to warp amount
    [WaveTable.cpp, WaveTable.h, configManager.cpp]
2024-05-29 Apply a cross-fade when changing warp type
    [WaveTable.cpp, WaveTable.h, lcd.cpp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]
2024-05-31 Started implementing config on multiple sectors
    Fixed wave table Position CV not working for channel B in additive mode
    [WaveTable.cpp, configManager.cpp]
2024-06-01 Cleaned project; implemented multi-sector config saving
    [Retrospector_Components.kicad_pcb, Retrospector_Components.kicad_sch, Retrospector_Components.sch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]
2024-06-02 Warp button inverts channel B
    [WaveTable.cpp, WaveTable.h, main.cpp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]
2024-06-02 Clean up channel B reverse button
    [WaveTable.cpp, WaveTable.h, initialisation.cpp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]
2024-06-02 Fixed display bug in channel B waveform
    [WaveTable.h]
2024-06-18 Bug fixes to wavetable code
    [WaveTable.cpp]
2024-06-19 Colour handling improvements; bug fixes
    - Workaround for wavetable size corruption in header
    - Fixed 16 bit samples playing back half volume
    - Tanh limit channel B output
    [WaveTable.cpp, WaveTable.h, lcd.h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]
2024-06-19 Added frame count display when changing wavetables
2024-06-20 Improvements to UI
    - Smoothed/quantised wavetable position
    - Fixes to file info display/clearing
    [WaveTable.cpp, WaveTable.h, ui.cpp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]
2024-06-21 Fixes to lock-ups in USB reset routine
    Also better handling for bad file data containing zero clusters after deleting file
    [USB.cpp, WaveTable.cpp]
2024-06-21 Fixed issue refreshing wavetable list after USB deletion
    Started adding support for fragmented wavetables
    Fixes for directory printing formatting
    [Kishoof_Components.kicad_sch]
2024-06-22 Fixing bugs in USB file handling and directory listing
    [FatTools.h, USB.cpp, USB.h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]
2024-06-23 Prevent Windows indexer accesses being saved unnecessarily
    +Formatting in safe mode updates header cache
    [FatTools.h, main.cpp]
2024-06-23 Fixes to config saving
    - Errors not correctly cleared
    - Program flash not reporting errors correctly
    [FatTools.h, WaveTable.cpp, configManager.cpp]
2024-06-24 Code clean up
    Fixed directory listing exceeding cluster size
    Output zero sample when USB write ongoing
    [Calib.cpp, ExtFlash.cpp, FatTools.h]
2024-06-24 More code clean up
    [Kishoof_Panel.kicad_pcb]
2024-07-12 Fixed wavetable parsing extending beyond size of directory
    [WaveTable.cpp]
2024-07-17 Added tool to fix wavetables with unaligned headers
    [FatTools.h, WaveTable.cpp, WaveTable.h]
2024-08-09 Updated 'Fix Unaligned' tool for more file types
    [USB.cpp, WaveTable.cpp]
2024-10-09 Fixed minor bug where initial value in calibration was wrong
    [Calib.cpp]
2024-11-29 Added calibration defaults
2025-05-13 Added fix for USB not enumerating on MacOS and Linux
    [USB.cpp]
2025-06-24 Provisional fix for USB locking up copying files off module
    [FatTools.h]
2025-07-06 Updates to improve hanging and crashes when transferring files over USB
    [FatTools.h, Kishoof.ioc, USB.cpp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]
2025-07-06 Updated Controls PCB to fix VCA normalisation problem
    [Kishoof_Controls-B_Cu.gbr, Kishoof_Controls-B_Mask.gbr, Kishoof_Controls-B_Paste.gbr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]

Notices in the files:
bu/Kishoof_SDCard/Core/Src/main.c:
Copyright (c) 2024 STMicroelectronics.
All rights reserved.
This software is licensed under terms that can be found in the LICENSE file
